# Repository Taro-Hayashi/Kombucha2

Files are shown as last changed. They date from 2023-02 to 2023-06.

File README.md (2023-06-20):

# Kombucha ジョイスティック 左手向けビルドガイド（[右手向け](README_R.md)）
- [キット内容](#キット内容)
- [準備](#準備)
- [はんだ付け](#はんだ付け)
- [組み立て](#組み立て)
- [カスタマイズ](#カスタマイズ)
- [meishi Trackball Moduleを使う](#meishi-Trackball-Moduleを使う)
- [その他](#その他)

## キット内容
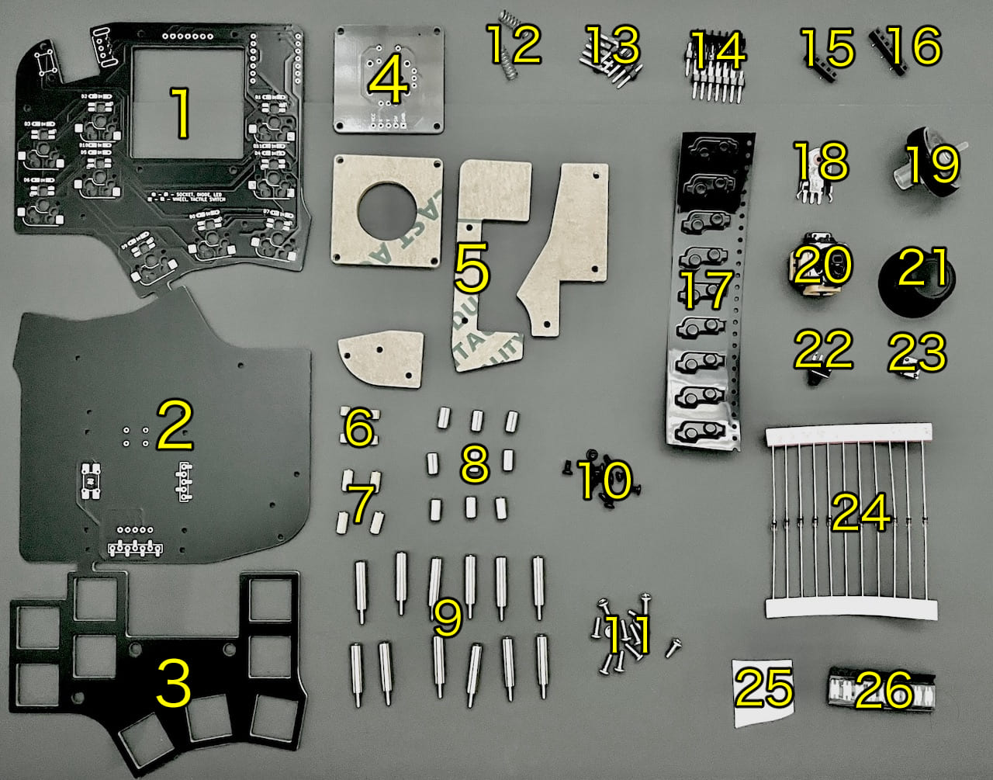
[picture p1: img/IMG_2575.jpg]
  
||部品名|数| |
|-|-|-|-|
|1|メインボード|1||
|2|トッププレート|1||
|3|ボトムプレート|1||
|4|ジョイスティック基板|1||
|5|アクリルプレート|4||
|6|スペーサー（細）（短）|4|黄銅・3mm|
|7|スペーサー（細）（長）|4|黄銅・7mm|
|8|スペーサー（太）（短）|9|ステンレス・7mm|
|9|スペーサー（太）（長）|12|ステンレス・16mm|
|10|ねじ（短）|14|黒|
|11|ねじ（長）|12|銀|
|12|スプリング|2||
|13|ピンヘッダ（短）|2|5ピン|
|14|ピンヘッダ（長）|1|7 or 8ピン|
|14|7ピンヘッダ|2|XIAO RP2040用|
|15|ピンソケット（短）|1||
|16|ピンソケット（長）|1||
|17|スイッチソケット|9||
|18|ホイールエンコーダー|1|11mm|
|19|ホイール|1||
|20|ジョイスティック|1||
|21|キャップ|1||
|22|タクタイルスイッチ|1|7.5mm|
|23|タクタイルスイッチSMD|1|7mm|
|24|ダイオード|11||
|25|LED|9||
|26|ゴム足|4|

### キット以外に必要なもの
|部品名|数||
|-|-|-|
|XIAO RP2040|1|[TALP KEYBOARD](https://talpkeyboard.net/items/63534f58f5197322fceb6487)、[秋月電子通商](https://akizukidenshi.com/catalog/g/gM-17044/)|
|Cherry MX互換キースイッチ|1|[TALP KEYBOARD](https://talpkeyboard.net/?category_id=5f2d0726afaa9d40152b2cec)、[遊舎工房](https://shop.yushakobo.jp/search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)|
|Cherry MX互換キーキャップ（1U）|1|[TALP KEYBOARD](https://stores.jp/search?q=チェリーMX&store=talpkeyboard)、[遊舎工房](https://shop.yushakobo.jp/collections/keycaps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特殊&filter.v.price.gte=&filter.v.price.lte=)|
|Type-C USB ケーブル|1|[遊舎工房](https://shop.yushakobo.jp/products/usb_type_a_to_c_cable?_pos=3&_sid=d2e0de26b&_ss=r)、[秋月電子通商](https://akizukidenshi.com/catalog/g/gC-13563/)、100円均一など|
 
### 必要な工具
|工具名|
|-|
|はんだごて|
|はんだ|
|精密ドライバー|
|ニッパー|

## 準備
<!-- 
### プレートを切り離す
メインボード、トッププレート、ボトムプレートを切り離します。そのまま折るだけでも割れますがカッターなどで切れ目を入れると入れる力が少なくて済みます。  
![](img/) 
ニッパーでバリを取り切断面を棒やすりで綺麗にします。  
![](img/)
-->
### 左右を決める
このキットは基板の表裏を変えることで左手用と右手用を作り分けることができます。   
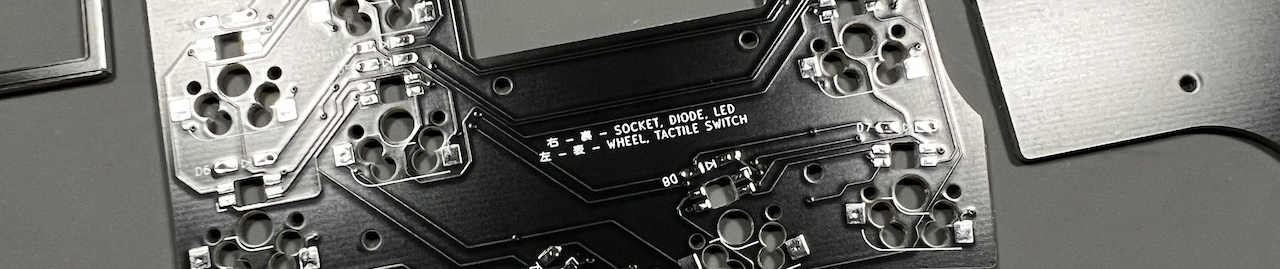
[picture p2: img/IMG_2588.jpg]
 
どちらの面にどの部品を実装するかが基板に書いてあるので参考にしてください。   

基板には初期型と後期型が存在し、2023年5月分の在庫では混在しています（今後は後期型に統一されます）。後期型の場合基板に書いてありますのでご確認ください。

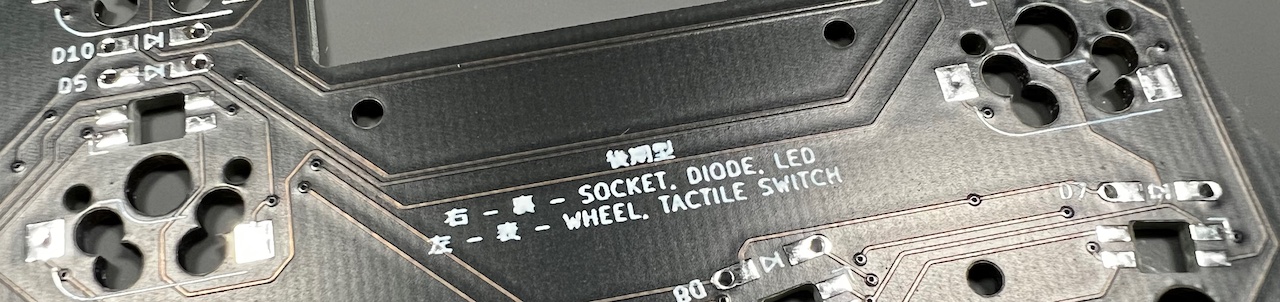
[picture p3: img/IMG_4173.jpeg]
 

### XIAO RP2040にテストファームウェアを書き込む  
こちらのファイルをダウンロードしてください。  
- [tarohayashi_kombucha_stick_default.uf2](https://github.com/Taro-Hayashi/Kombucha2/releases/download/0.20.7/tarohayashi_kombucha_stick_default.uf2)

基板上の右のBのボタンを押しながらPCに接続するとRPI-RP2というドライブとして認識されます。  
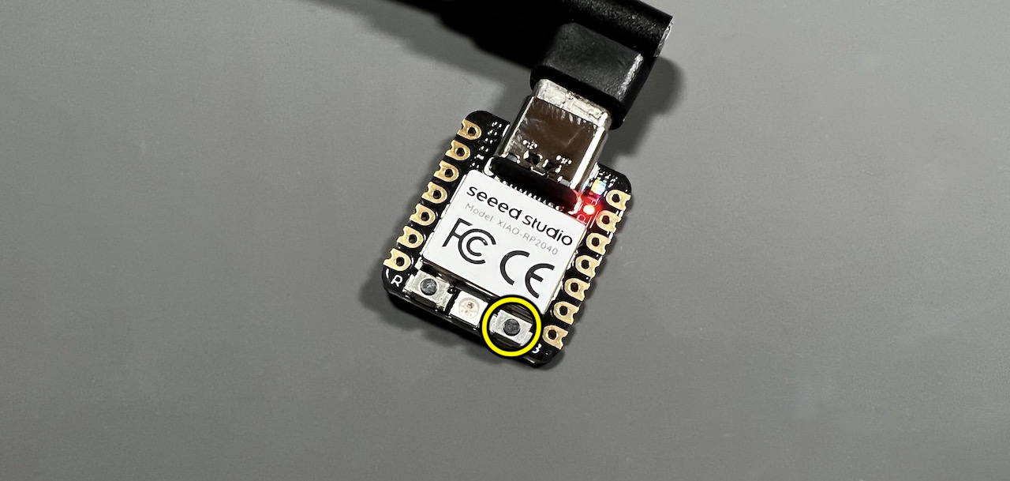
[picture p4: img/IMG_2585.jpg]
 
ダウンロードしたファイルを書き込むとXIAO RP2040をキーボードとして使えるようになります。  

## はんだ付け
### ボトムプレートのはんだ付け
左右を確認してボトムプレートにピンソケット2つをはんだ付けします。    
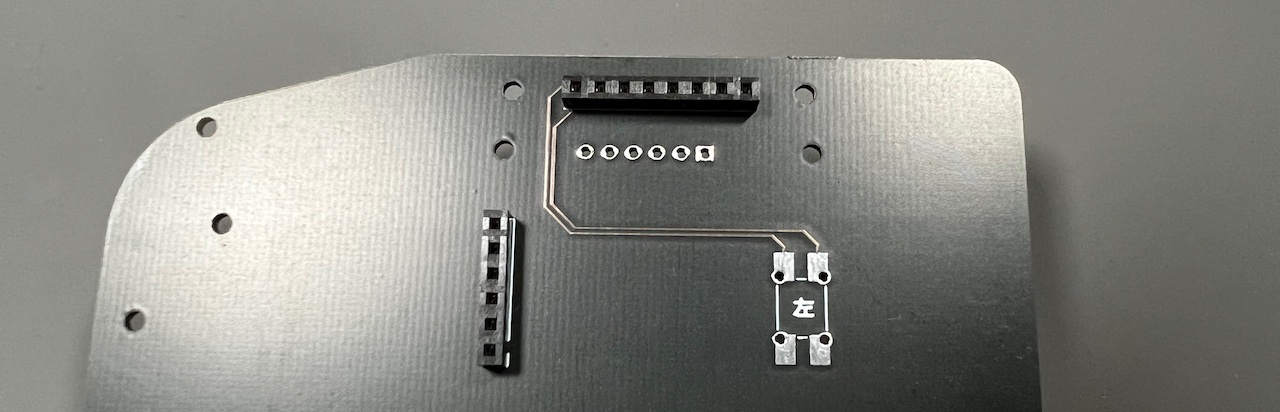
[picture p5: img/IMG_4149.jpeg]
 

ボトムプレートのピンソケットと同じ面にスペーサー（太）（短）をねじ（短）で止めます。黄丸の４箇所にはスペーサー（細）（長）を使います。  
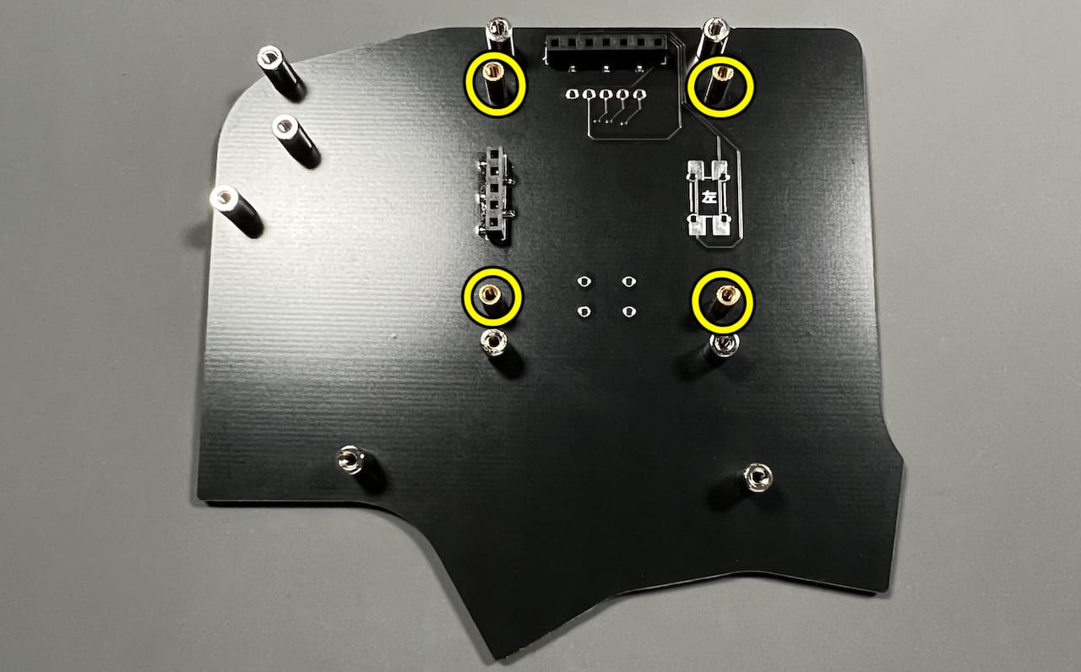
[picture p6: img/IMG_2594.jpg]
 
反対の面にはゴム足を貼ります。  
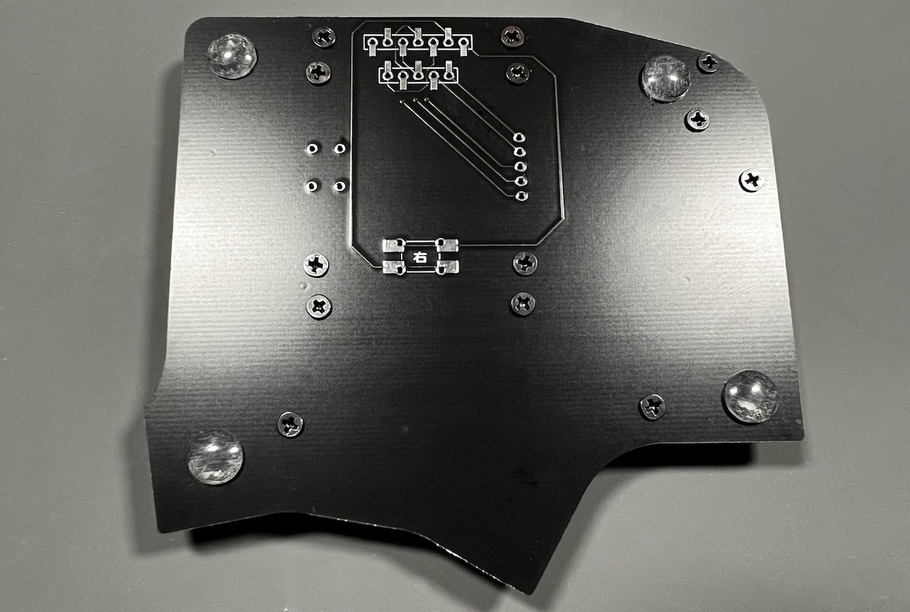
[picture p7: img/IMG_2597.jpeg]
 

### ジョイスティック基板のはんだ付け
ジョイスティック基板にジョイスティックをはんだ付けします。  
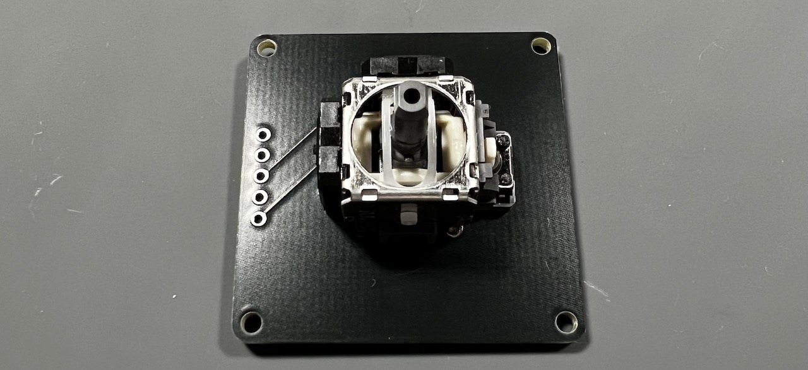
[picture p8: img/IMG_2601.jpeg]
 
ジョイスティックが中央に戻らないことがありますが、アクリルプレートを取り付ける前の正常な動作です。  

ボトムプレートのピンソケットに5ピンヘッダを立てます。短い方を差しました。  
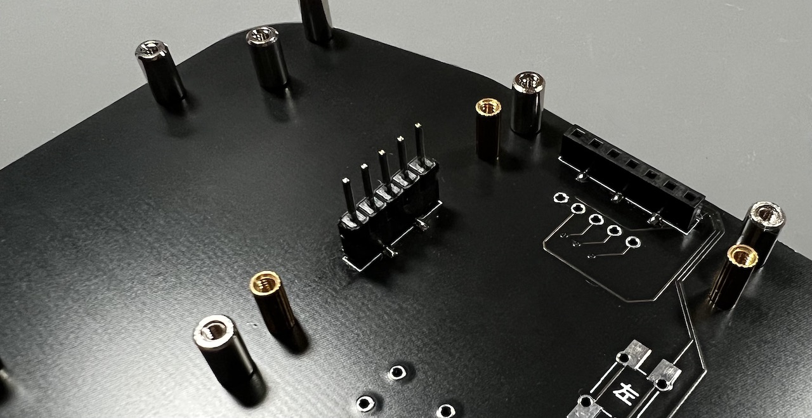
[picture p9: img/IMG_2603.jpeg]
 
後期型の場合は画像のピンを開けて差し込んでください。違っているとネジ穴が合わないので確認してから半田付けしてください。
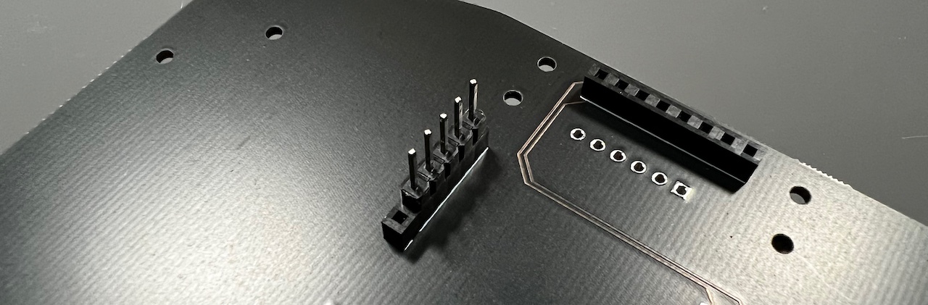
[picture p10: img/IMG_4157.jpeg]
 

ジョイスティック基板をスペーサー（細）（長）の上にのせ、スペーサー（太）（長）でボトムプレートに固定します。  
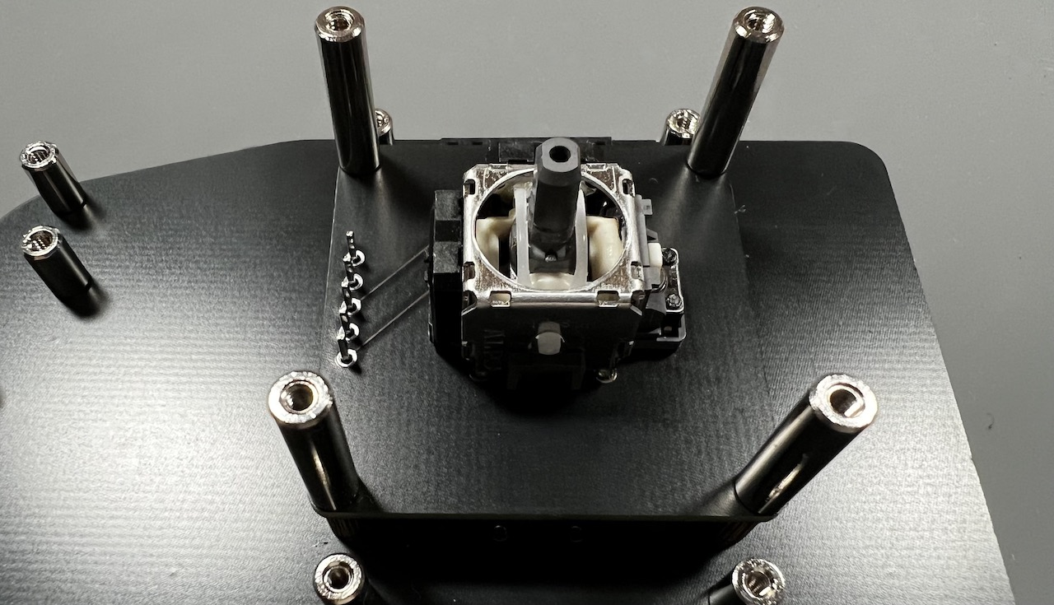
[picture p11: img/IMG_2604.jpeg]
 

飛び出たピンヘッダをニッパーで切りはんだ付けしましょう（ギリギリまで切りすぎるとうまくはんだ付けできないことがあります）。   
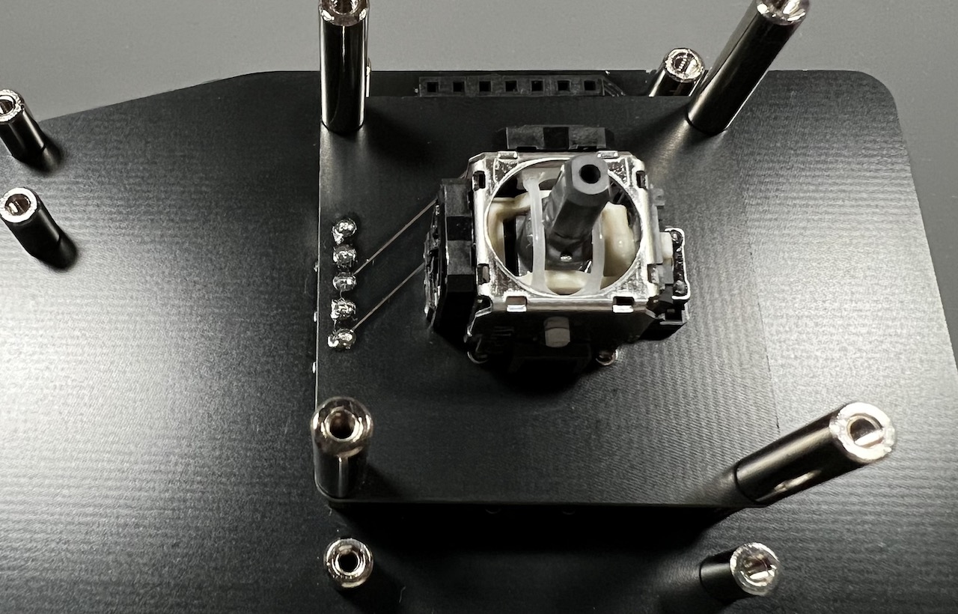
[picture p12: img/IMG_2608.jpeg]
 

ジョイスティックにキャップを取り付けます。  
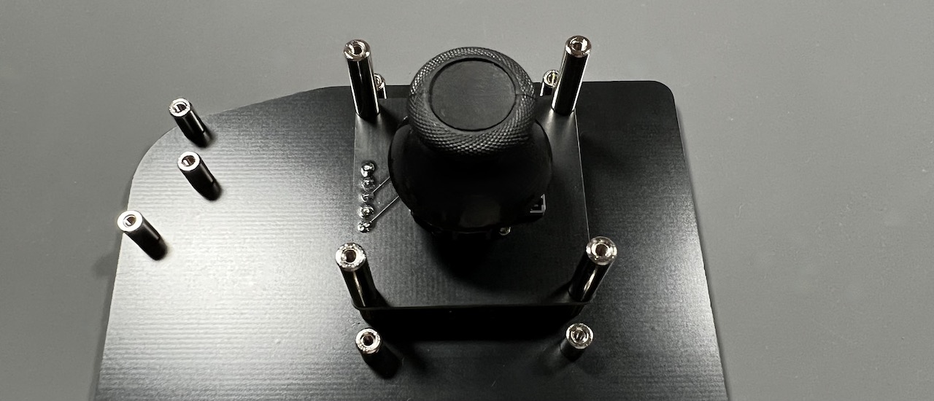
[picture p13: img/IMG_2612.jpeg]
 

### メインボードのはんだ付け
LEDをはんだ付けします。欠けている方向と白い線が合うように置きます。  
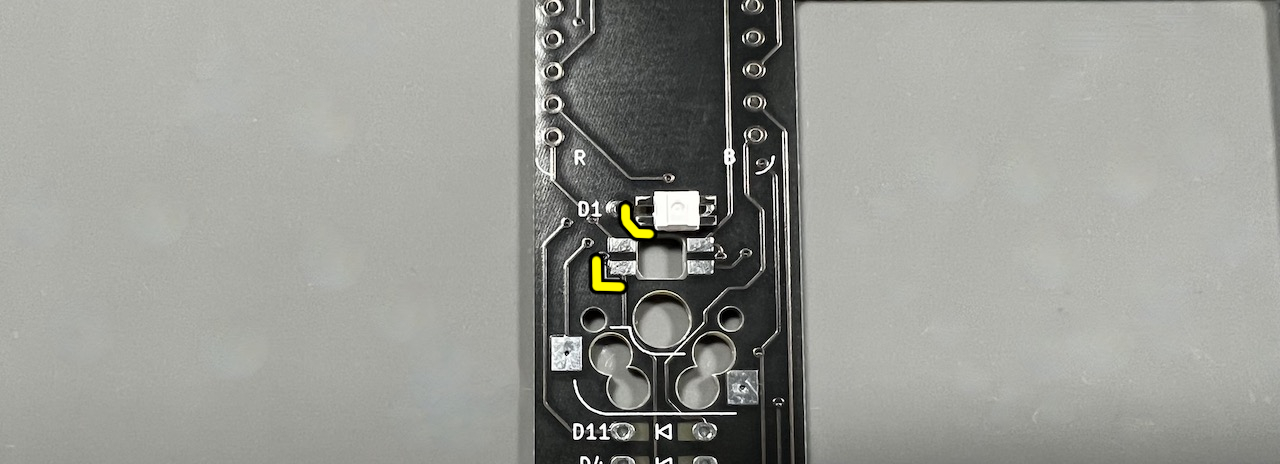
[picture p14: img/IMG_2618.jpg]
   

XIAO RP2040を7ピンヘッダーではんだ付けします。両面をはんだ付けします。  
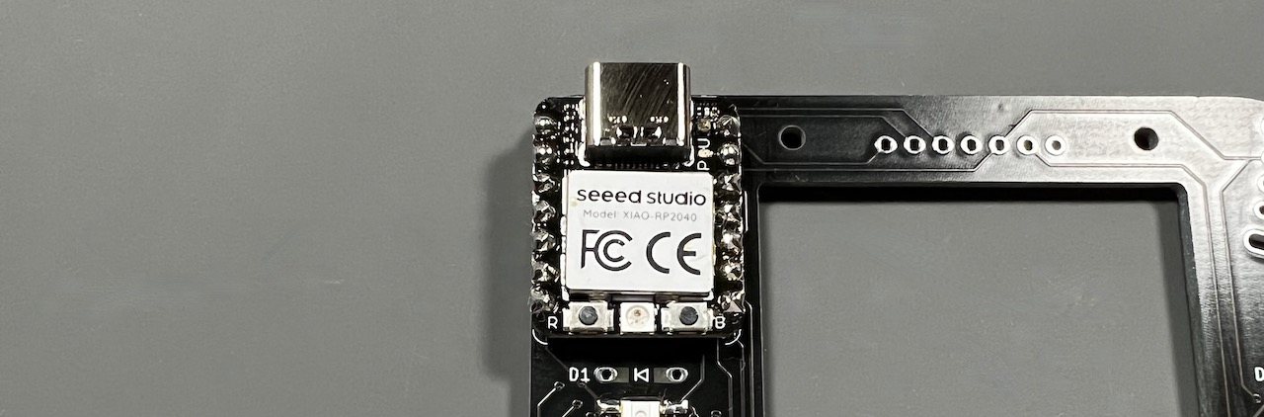
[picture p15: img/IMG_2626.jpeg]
 

USBケーブルを接続してLEDが発光することを確かめてください。光らない場合は向きが間違っていたりどこかでショートしていたりはんだ付けが足りない可能性があります。  
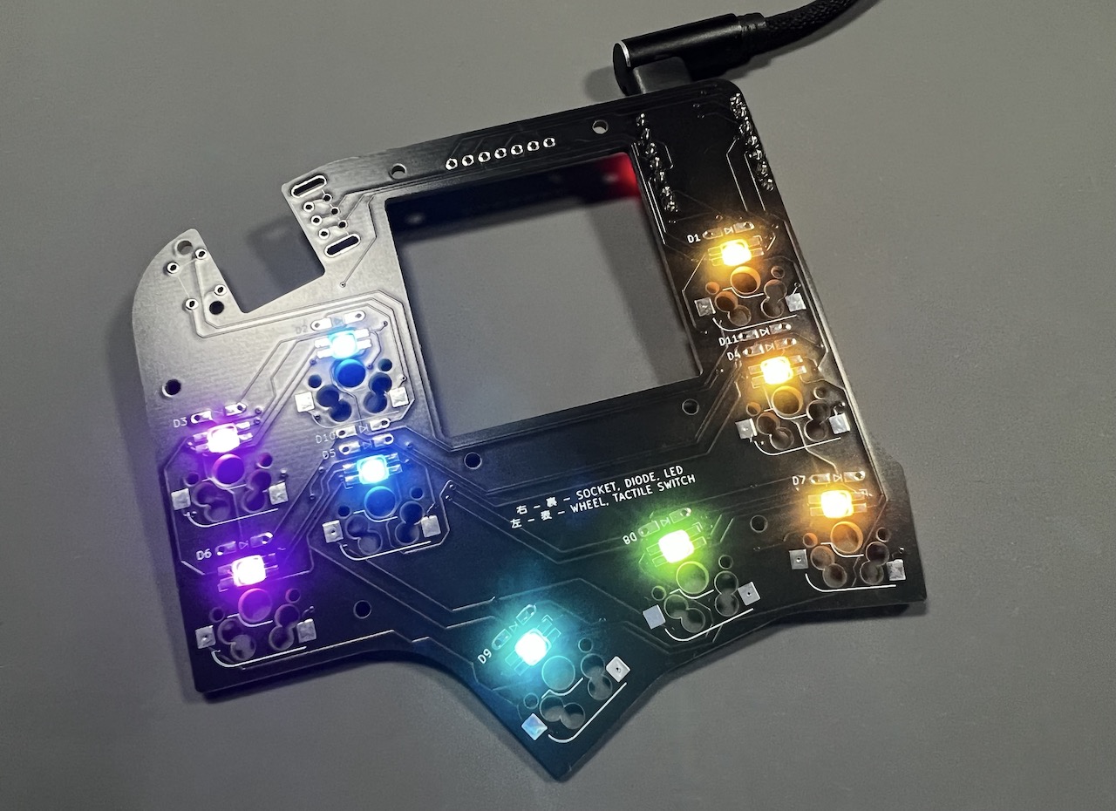
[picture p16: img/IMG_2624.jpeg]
  
  
USBケーブルを抜いてください。はんだ付けの作業は通電していない状態で行います。  
この後も部品を取り付けるごとにその部品の動作を確認するとトラブルの原因を突き止めやすいです。   
    
ダイオードを折り曲げて差し込み、固定するためにさらに曲げます。表裏を指定してありますがどちら側でも構いません。  
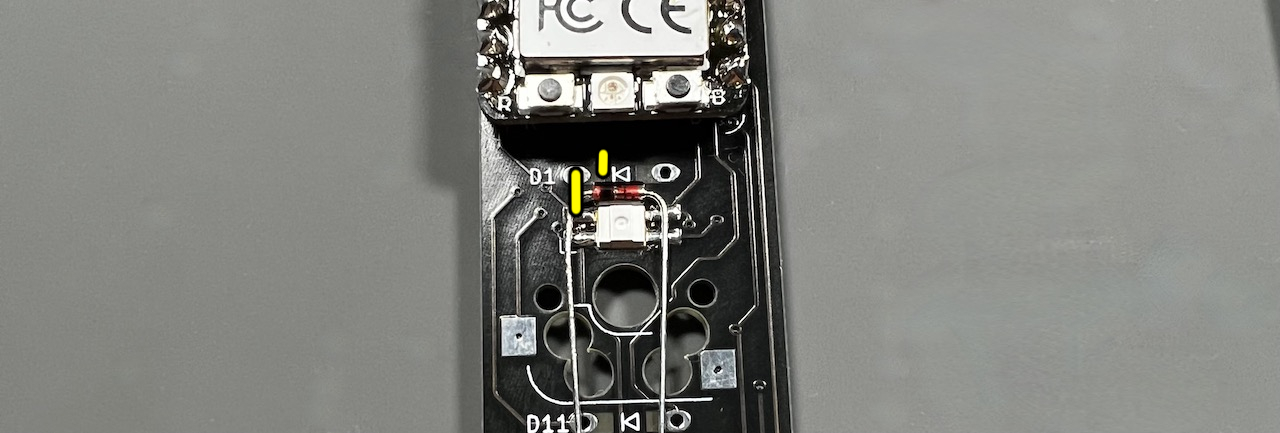
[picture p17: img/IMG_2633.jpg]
 
ダイオードには向きがあるので、黒線と基板の矢印の向きを合わせてください。  

はんだ付けをしたら足をニッパーで切ります。  
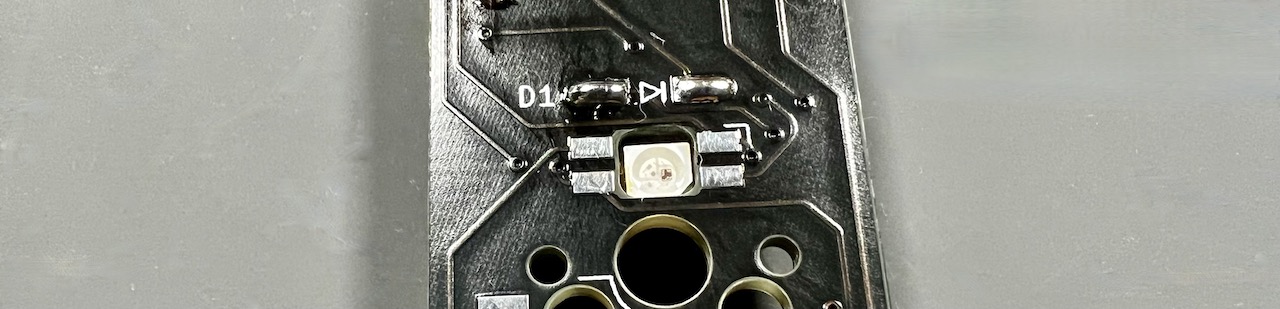
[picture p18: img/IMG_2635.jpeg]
 

スイッチソケットをはんだ付けします。裏表に注意してください。  
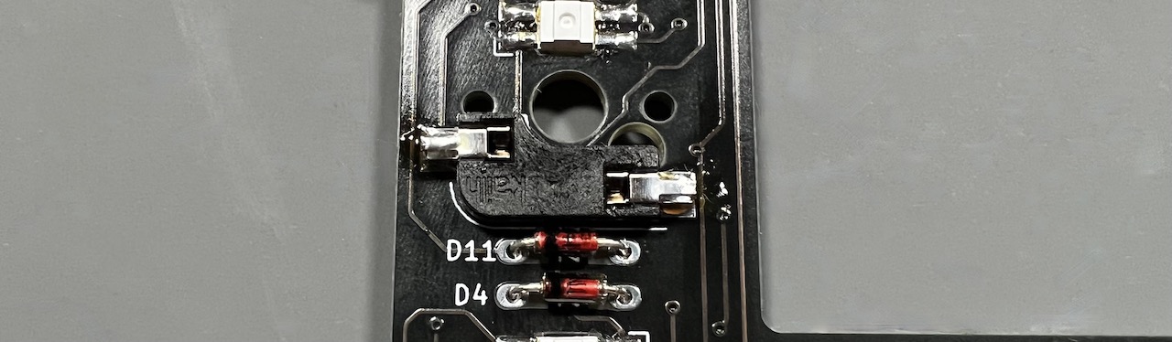
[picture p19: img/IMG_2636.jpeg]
 

メインボードにホイールエンコーダーとタクタイルスイッチ（足が下に伸びている方）をはんだ付けします。表裏に注意してください。  
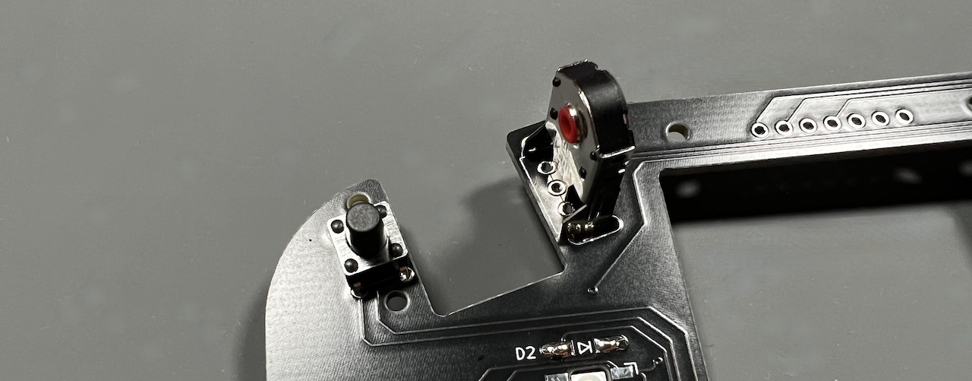
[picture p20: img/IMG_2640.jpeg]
 

ボトムプレートにピンヘッダを差し込みます。  
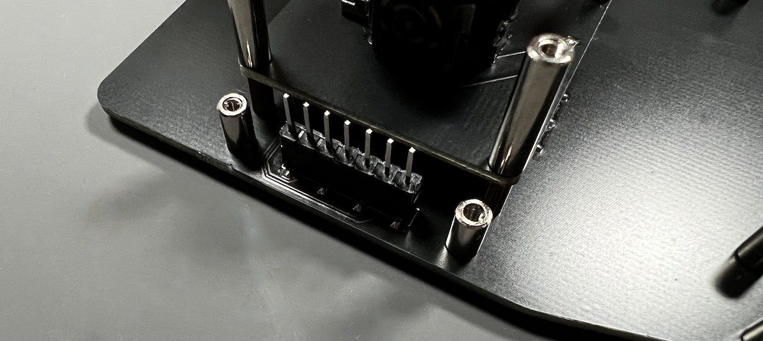
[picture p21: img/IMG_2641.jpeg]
 

ボトムプレートにメインボードを載せ、スペーサー（太）（長）でボトムプレートに固定します。トッププレートで隠れる黄丸の一箇所だけはねじ（短）で止めます。  
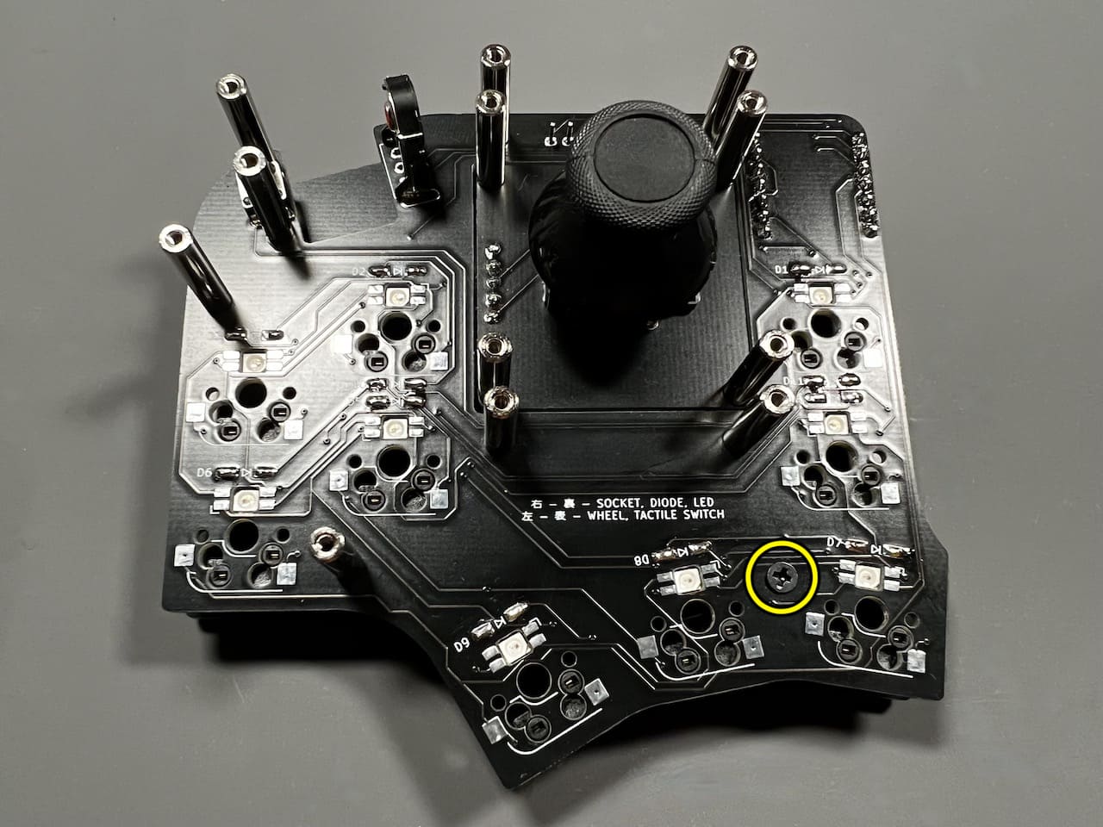
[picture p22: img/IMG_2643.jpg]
 
飛び出たピンヘッダをニッパーで切ってはんだ付けしましょう。テストファームウェアではジョイスティックは動作しません。  

トッププレートの4隅にスイッチを差し込みます。差し込みが硬い場合はここですべてのスイッチを固定してしまう方がいいかもしれません（スイッチの種類によって変わります）。  
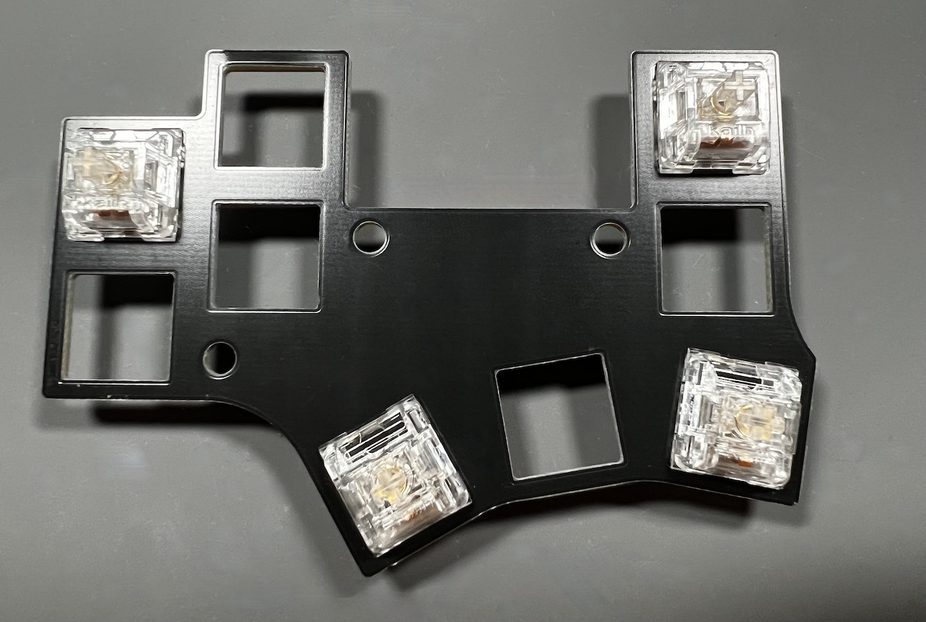
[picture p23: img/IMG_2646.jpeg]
 

スペーサーを通してメインボードに乗せ、キースイッチがスイッチソケットに入るように押し込みます。  
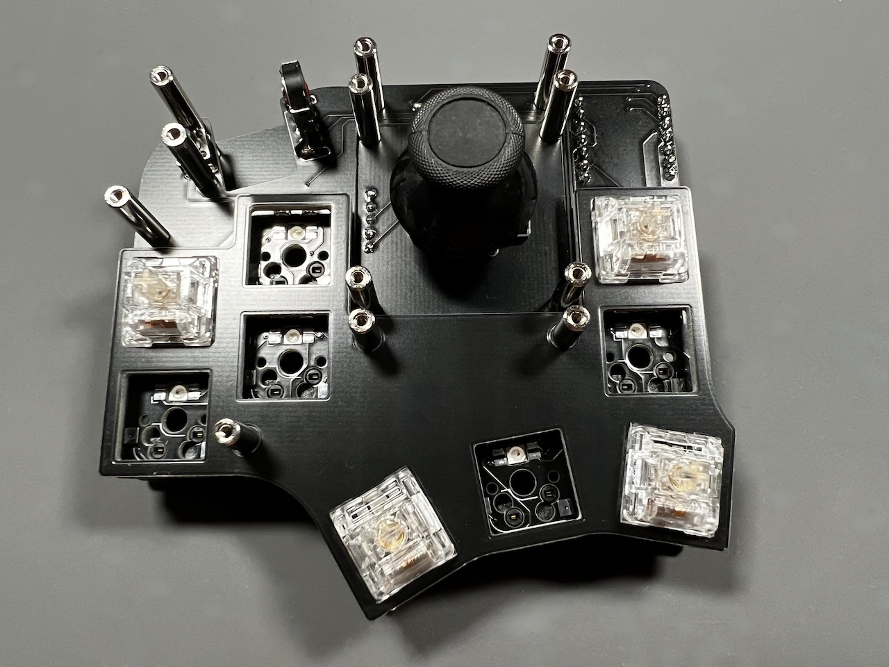
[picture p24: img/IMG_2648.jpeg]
 
キースイッチのピンが曲がらないように気をつけてください。  

全てのスイッチを差し込み、ホイールをホイールエンコーダーに差し込みます。  
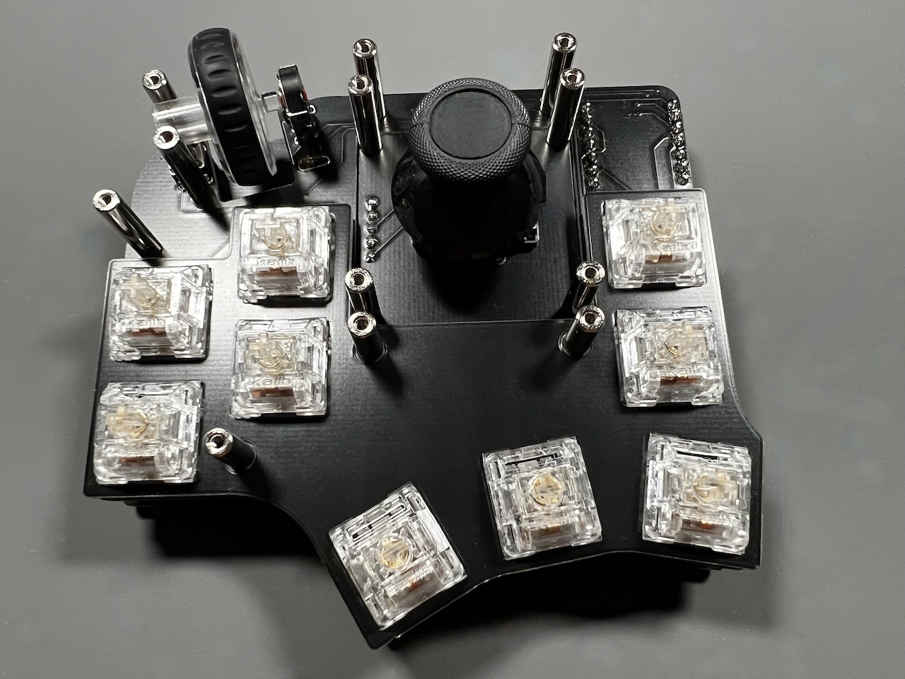
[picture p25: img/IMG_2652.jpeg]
 

アクリルプレートから保護フィルムを剥がして、ねじ（長）で止めます。  
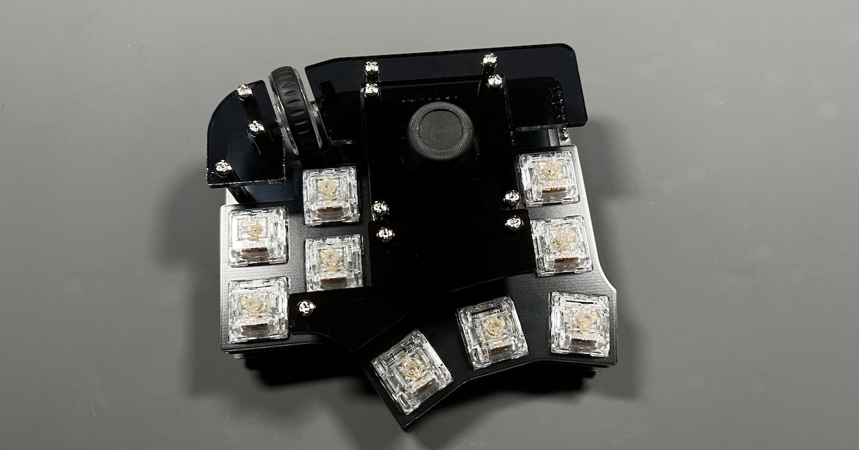
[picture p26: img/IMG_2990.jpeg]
 

キーキャップをつけて完成です。
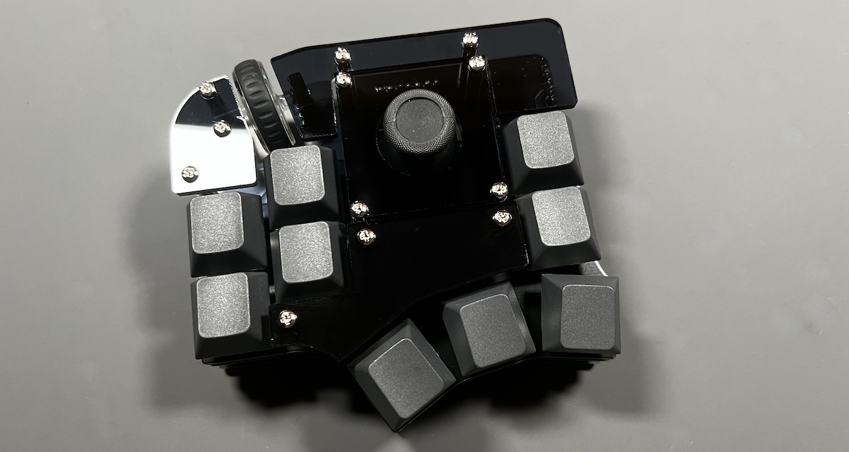
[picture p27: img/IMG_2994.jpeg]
 
こちらのファームウェアを書き込んでください。XIAO RP2040のBのスイッチを押す代わりに、XIAO RP2040に一番近いキーを押しながらUSBケーブルを繋ぐことでRPI-RP2のドライブを出すことが出来ます。  
- [tarohayashi_kombucha_stick_stick.uf2](https://github.com/Taro-Hayashi/Kombucha2/releases/download/0.20.7/tarohayashi_kombucha_stick_stick.uf2)
- 後期型向け [tarohayashi_kombucha_stick_stick.uf2](https://github.com/Taro-Hayashi/Kombucha2/releases/download/0.20.8/tarohayashi_kombucha_stick_stick.uf2)

## カスタマイズ
LEDを消したい時は親指クラスタ（最下段）の奥のキーを押しながらジョイスティックを押し込んでください。  
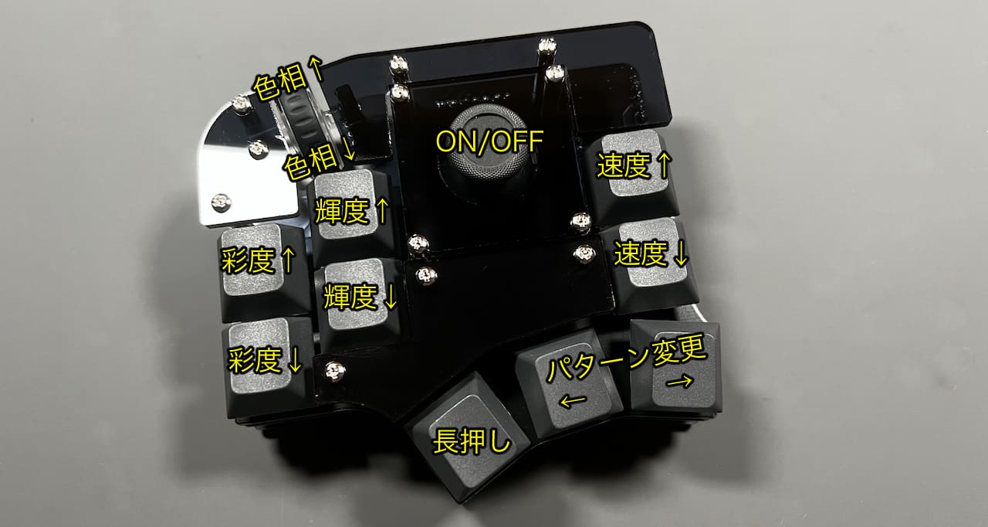
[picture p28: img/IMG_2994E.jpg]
 

ジョイスティックを含めた全てのキーはVIAというWebサイト（もしくはアプリケーション）で好きなものに変更することができます。  
こちらのJSONファイルをダウンロードしてください。 
- [kombucha.json](https://github.com/Taro-Hayashi/Kombucha2/releases/download/0.20.0/kombucha.json)

Google Chrome（Microsoft Edge）を利用して下記webサイトにアクセスするか、VIAのアプリケーションをダウンロードして起動してください。  
- [Web版VIA（Google Chromeでアクセスしてください）](https://usevia.app/#/design)
- [アプリ版VIA](https://github.com/the-via/releases/releases)

DESIGNタブのLoadでダウンロードしたJSONファイルを読み込ませるとキーの変更が出来るようになります（アプリ版ではまずShow Design tabをオンにしてください）。  
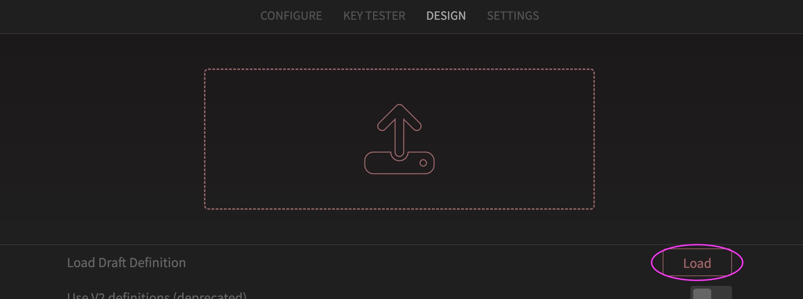
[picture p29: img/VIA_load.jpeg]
  
CONFIGUREタブのAuthorize device+からKombuchaを追加してください。  

### 左右の変更
LAYOUTSから見た目の左右を変更することができます。  
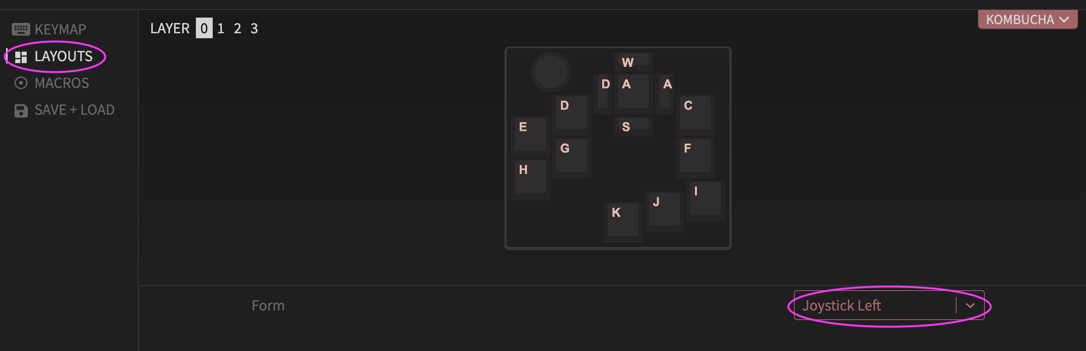
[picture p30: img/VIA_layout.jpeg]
  

### ホイールの割り当てキー
キーマップ変更画面で上部の丸をクリックするとホイールを回転させた時と押し込んだ時に入力されるキーを変更することができます。  
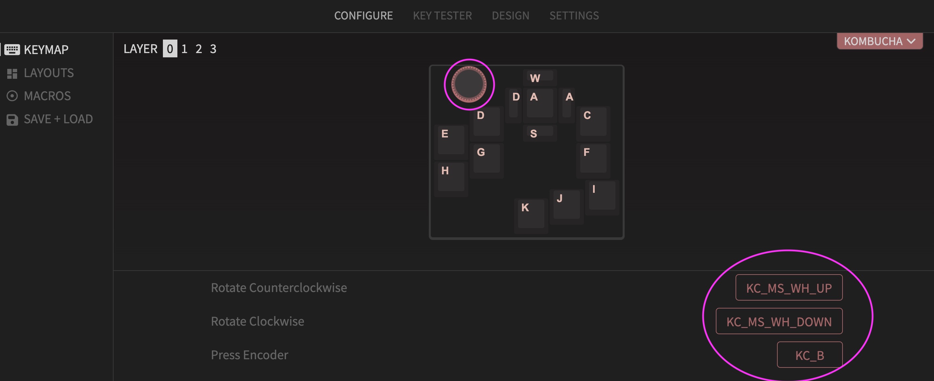
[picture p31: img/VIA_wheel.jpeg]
  

### その他の利用方法
ジョイスティックでマウスカーソルを動かすことも可能で、その場合はこちらのファイルをダウンロードしてファームウェアを書き換えてください。 
- [tarohayashi_kombucha_stick_cursor.uf2](https://github.com/Taro-Hayashi/Kombucha2/releases/download/0.20.7/tarohayashi_kombucha_stick_cursor.uf2)
- 後期型向け [tarohayashi_kombucha_stick_cursor.uf2](https://github.com/Taro-Hayashi/Kombucha2/releases/download/0.20.8/tarohayashi_kombucha_stick_cursor.uf2)

認識が不安定ですが、こちらのファームウェアを書き込むことでKombuchaをゲームパッドとして認識させることもできます。  
- [tarohayashi_kombucha_sitck_joypad_fix.uf2](https://github.com/Taro-Hayashi/Kombucha2/releases/download/0.20.7/tarohayashi_kombucha_stick_joypad.uf2)

標準では親指クラスタの真ん中のキーを長押しするとカーソル/ジョイパッドの方向を変更できます。
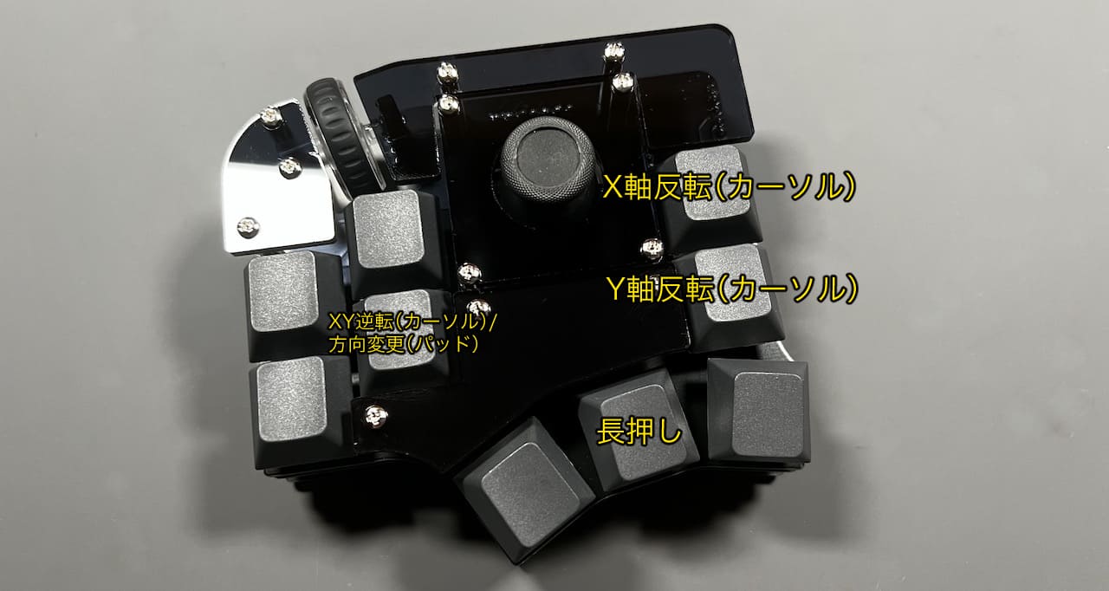
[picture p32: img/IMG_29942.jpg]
 
|機能（カーソル）|機能（パッド）|キーコード|
|-|-|-|
|X軸反転||CUSTOM(65)|
|Y軸反転||CUSTOM(66)|
|XY逆転|方向変更|CUSTOM(67)|

SPECIALタブのAnyで割り当てることができます。
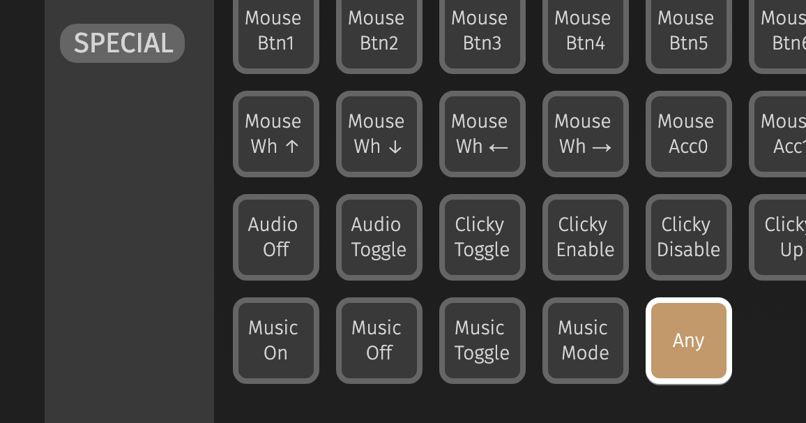
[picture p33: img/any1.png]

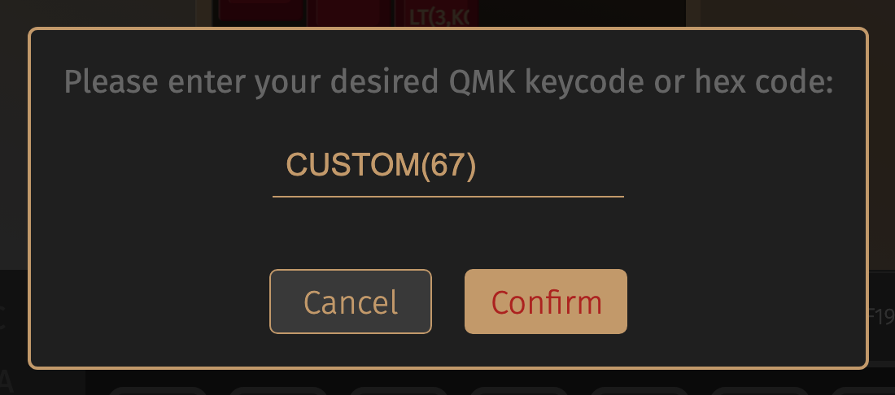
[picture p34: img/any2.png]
 
  
#### ジョイスティックの補正
WindowsではスタートメニューにJOY.CPLと打ち込むとスティックの補正ができます。  
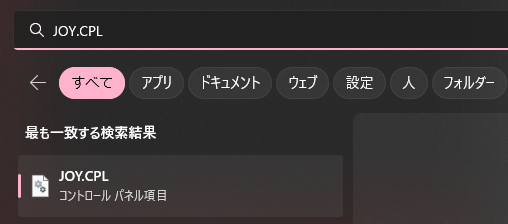
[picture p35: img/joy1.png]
   
プロパティから調整を選びウィザードに従ってください。  
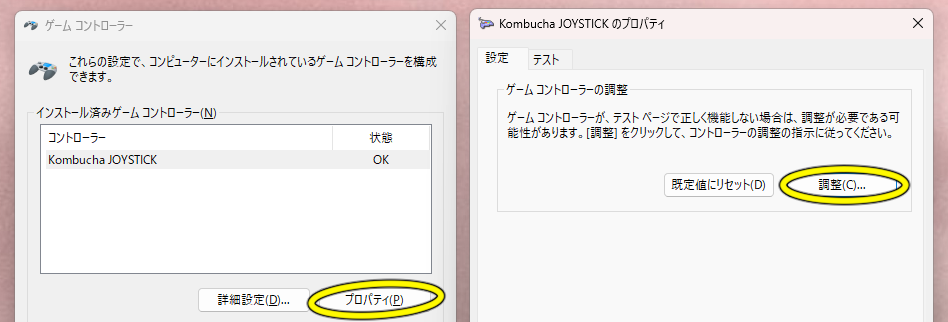
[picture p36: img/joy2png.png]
    
上手く動かない場合はゲームパッドとしてではなく通常のファームウェアにカーソルキーやWASDを割り当ててお使いください。  

## meishi Trackball Moduleを使う
### はんだ付け
一度分解し、ボトムプレートにタクタイルスイッチSMDをはんだ付けします。
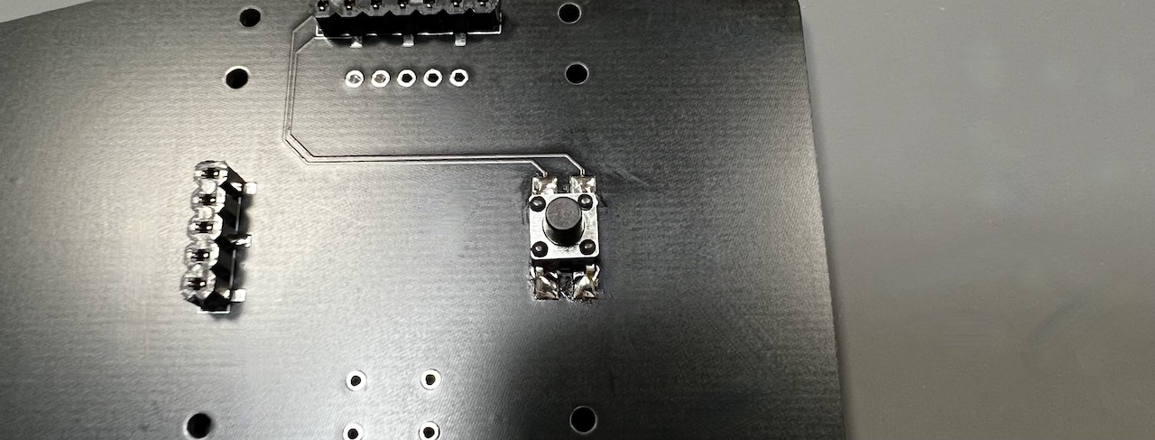
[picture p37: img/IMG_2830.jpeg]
  
ピンヘッダーが有る側の2箇所はスペーサー（細）（長）、無い側の2箇所はスペーサー（細）（短）をねじ止めします。
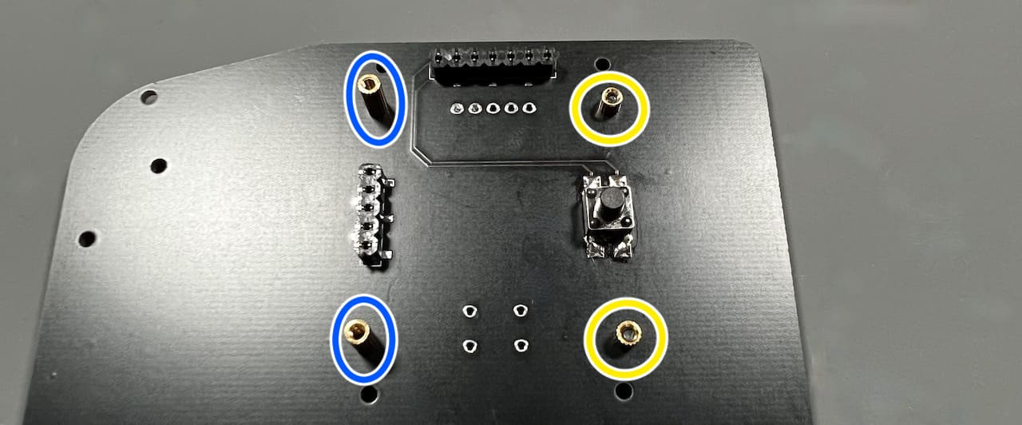
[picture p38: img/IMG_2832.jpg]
 
meishi Trackball Moduleを基板から切り離してください。  
[meishi Trackball Module互換基板を使う場合はこちらをご覧ください。](mTM.md)  
  
ジョイスティックの時と同様にピンヘッダを立てモジュール付属のねじを使って基板の位置を決めたらはんだ付けします。
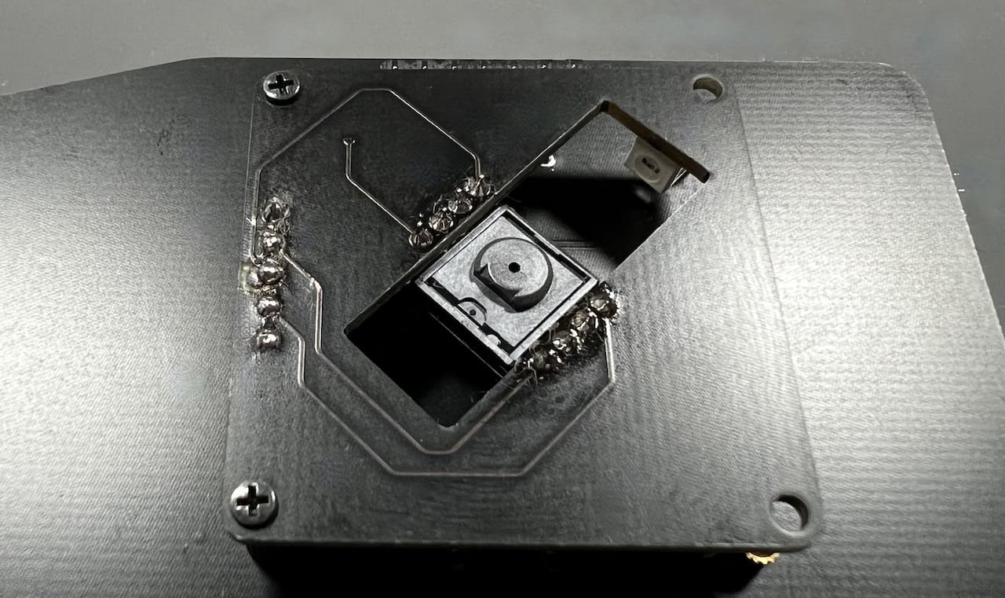
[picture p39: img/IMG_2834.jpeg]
  
後期型の場合は画像のピンを開けて差し込んでください。違っているとネジ穴が合わないので確認してから半田付けしてください。
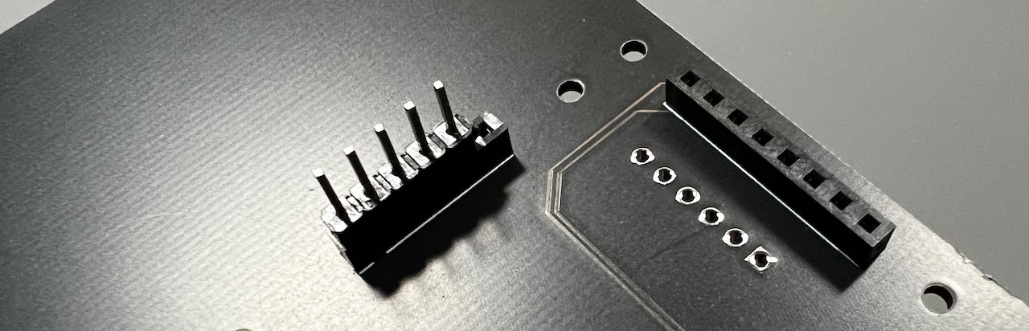
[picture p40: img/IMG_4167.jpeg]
  

はんだ付けをしたらねじを一度はずしてモジュール基板を取り外し、センサーの保護フィルムをはがしてレンズとボールケースを取り付けます。  
  

ピンヘッダーのない側にスペーサー（細）（短）をねじで止めます。  

スペーサーの上にスプリングを立てます。

ねじでスペーサー（細）（長）側も止めるとボールのクリックができるようになります。

組み立て直したら完成です。


ファームウェアはこちらをお使いください。  
- [tarohayashi_kombucha_ball_via.uf2](https://github.com/Taro-Hayashi/Kombucha2/releases/download/0.20.7/tarohayashi_kombucha_ball_via.uf2)

### トラックボールの調整
標準では親指クラスタの真ん中のキーを押しながらボールの左右のキーを押すとセンサーの感度（CPI）を増減できます。その下のキーを押すとマウスカーソルの上下左右の十字方向と10°の微調整が可能です。

|機能|キーコード|
|-|-|
|CPI増|CUSTOM(65)|
|CPI増|CUSTOM(66)|
|角度増|CUSTOM(67)|
|角度減|CUSTOM(67)|

SPECIALタブのAnyで割り当てることができます。

 

## その他
### ファームウェアのフォルダ
- https://github.com/Taro-Hayashi/qmk_firmware/tree/tarohayashi/keyboards/tarohayashi/kombucha

### ファームウェアまとめ
※5/21 後期版向けのファームウェアを追加しました。
- テスト用 [tarohayashi_kombucha_stick_default.uf2](https://github.com/Taro-Hayashi/Kombucha2/releases/download/0.20.7/tarohayashi_kombucha_stick_default.uf2)
- スティックにキー割り当て [tarohayashi_kombucha_stick_stick.uf2](https://github.com/Taro-Hayashi/Kombucha2/releases/download/0.20.7/tarohayashi_kombucha_stick_stick.uf2)
- スティックにキー割り当て（後期型向け） [tarohayashi_kombucha_stick_stick.uf2](https://github.com/Taro-Hayashi/Kombucha2/releases/download/0.20.8/tarohayashi_kombucha_stick_stick.uf2)
- スティックにマウスカーソル [tarohayashi_kombucha_stick_cursor.uf2](https://github.com/Taro-Hayashi/Kombucha2/releases/download/0.20.7/tarohayashi_kombucha_stick_cursor.uf2)
- スティックにマウスカーソル（後期型向け） [tarohayashi_kombucha_stick_cursor.uf2](https://github.com/Taro-Hayashi/Kombucha2/releases/download/0.20.8/tarohayashi_kombucha_stick_cursor.uf2)
- ジョイパッド[tarohayashi_kombucha_sitck_joypad.uf2](https://github.com/Taro-Hayashi/Kombucha2/releases/download/0.20.8/tarohayashi_kombucha_stick_joypad.uf2)
- トラックボール [tarohayashi_kombucha_ball_via.uf2](https://github.com/Taro-Hayashi/Kombucha2/releases/download/0.20.8/tarohayashi_kombucha_ball_via.uf2)

### VIA用JSON
- [kombucha.json](https://github.com/Taro-Hayashi/Kombucha2/releases/download/0.20.0/kombucha.json)

### アクリルプレートのデータ
DXF、SVG、kicadファイルが入っています。
- [kombucha_acrylic.zip](https://github.com/Taro-Hayashi/Kombucha2/releases/download/0.19.12%2Fdevelop/kombucha_acrylic.zip)

### 謝辞
aki27さんのコードを参考にトラックボール用のファームウェアを書きました。
- URL　https://github.com/aki27kbd/qmk_firmware
- ライセンス https://github.com/aki27kbd/qmk_firmware/blob/master/LICENSE

### 販売サイト  
- BOOTH: https://tarohayashi.booth.pm/items/3252673

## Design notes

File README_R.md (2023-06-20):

# Kombucha ジョイスティック 右手向けビルドガイド（[左手向け](README.md)）
- [キット内容](#キット内容)
- [準備](#準備)
- [はんだ付け](#はんだ付け)
- [組み立て](#組み立て)
- [カスタマイズ](#カスタマイズ)
- [meishi Trackball Moduleを使う](#meishi-Trackball-Moduleを使う)
- [その他](#その他)

## キット内容
  
||部品名|数| |
|-|-|-|-|
|1|メインボード|1||
|2|トッププレート|1||
|3|ボトムプレート|1||
|4|ジョイスティック基板|1||
|5|アクリルプレート|4||
|6|スペーサー（細）（短）|4|黄銅・3mm|
|7|スペーサー（細）（長）|4|黄銅・7mm|
|8|スペーサー（太）（短）|9|ステンレス・7mm|
|9|スペーサー（太）（長）|12|ステンレス・16mm|
|10|ねじ（短）|14|黒・4mm|
|11|ねじ（長）|12|銀|
|12|スプリング|2||
|13|5ピンヘッダ|2||
|14|7ピンヘッダ|3||
|15|5ピンソケット|1||
|16|7ピンソケット|1||
|17|スイッチソケット|9||
|18|ホイールエンコーダー|1|11mm|
|19|ホイール|1||
|20|ジョイスティック|1||
|21|キャップ|1||
|22|タクタイルスイッチ|1|7.5mm|
|23|タクタイルスイッチSMD|1|7mm|
|24|ダイオード|11||
|25|LED|9||
|26|ゴム足|4|

### キット以外に必要なもの
|部品名|数||
|-|-|-|
|XIAO RP2040|1|[TALP KEYBOARD](https://talpkeyboard.net/items/63534f58f5197322fceb6487)、[秋月電子通商](https://akizukidenshi.com/catalog/g/gM-17044/)|
|Cherry MX互換キースイッチ|1|[TALP KEYBOARD](https://talpkeyboard.net/?category_id=5f2d0726afaa9d40152b2cec)、[遊舎工房](https://shop.yushakobo.jp/search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)|
|Cherry MX互換キーキャップ（1U）|1|[TALP KEYBOARD](https://stores.jp/search?q=チェリーMX&store=talpkeyboard)、[遊舎工房](https://shop.yushakobo.jp/collections/keycaps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特殊&filter.v.price.gte=&filter.v.price.lte=)|
|Type-C USB ケーブル|1|[遊舎工房](https://shop.yushakobo.jp/products/usb_type_a_to_c_cable?_pos=3&_sid=d2e0de26b&_ss=r)、[秋月電子通商](https://akizukidenshi.com/catalog/g/gC-13563/)、100円均一など|
 
### 必要な工具
|工具名|
|-|
|はんだごて|
|はんだ|
|精密ドライバー|
|ニッパー|

## 準備
<!-- 
### プレートを切り離す
メインボード、トッププレート、ボトムプレートを切り離します。そのまま折るだけでも割れますがカッターなどで切れ目を入れると入れる力が少なくて済みます。  
![](img/) 
ニッパーでバリを取り切断面を棒やすりで綺麗にします。  
![](img/)
-->
### 左右を決める
このキットは基板の表裏を変えることで左手用と右手用を作り分けることができます。   
 
どちらの面にどの部品を実装するかが基板に書いてあるので参考にしてください。   

基板には初期型と後期型が存在し、2023年5月分の在庫では混在しています（今後は後期型に統一されます）。  
後期型の場合基板に書いてありますのでご確認ください。作り方が少し変わり、使用するファームウェアが一部異なります。  
 

### XIAO RP2040にテストファームウェアを書き込む  
こちらのファイルをダウンロードしてください。  
- [tarohayashi_kombucha_stick_default.uf2](https://github.com/Taro-Hayashi/Kombucha2/releases/download/0.20.7/tarohayashi_kombucha_stick_default.uf2)

基板上の右のBのボタンを押しながらPCに接続するとRPI-RP2というドライブとして認識されます。  
 
ダウンロードしたファイルを書き込むとXIAO RP2040をキーボードとして使えるようになります。  

## はんだ付け
### ボトムプレートのはんだ付け
左右を確認してボトムプレートにピンソケット2つをはんだ付けします。  
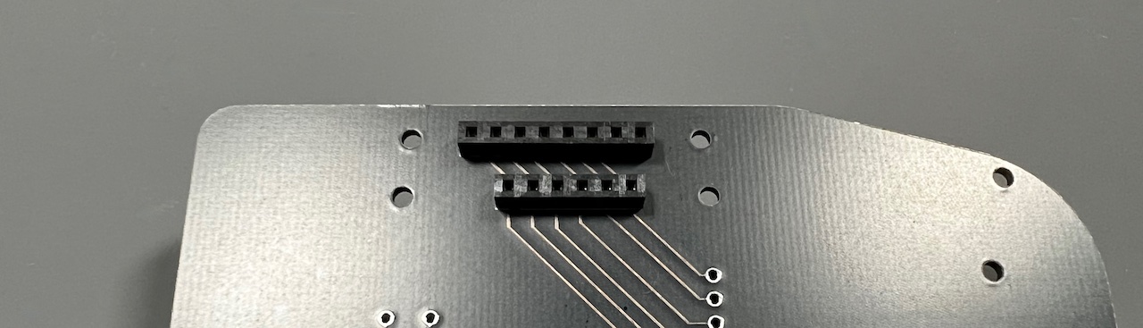
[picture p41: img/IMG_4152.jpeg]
 
位置決めが難しい場合や使っているうちに剥がれた場合などはDIPタイプのピンソケットも使用することができます。  

ボトムプレートのピンソケットと同じ面にスペーサー（太）（短）をねじ（短）で止めます。黄丸の４箇所にはスペーサー（細）（長）を使います。  
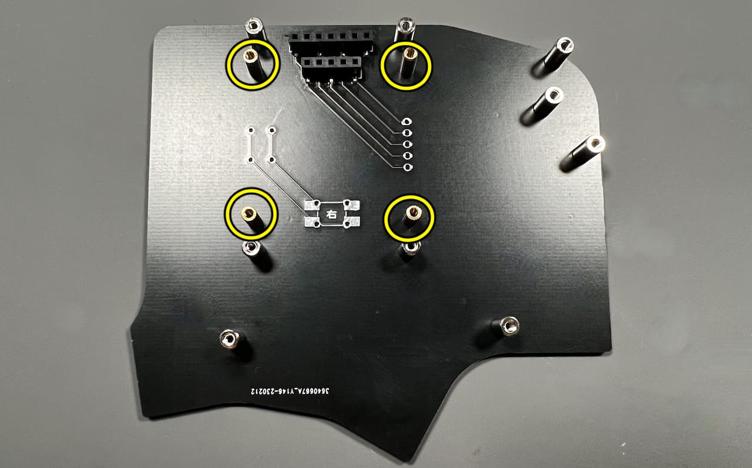
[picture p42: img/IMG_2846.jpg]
 
反対の面にはゴム足を貼ります。  
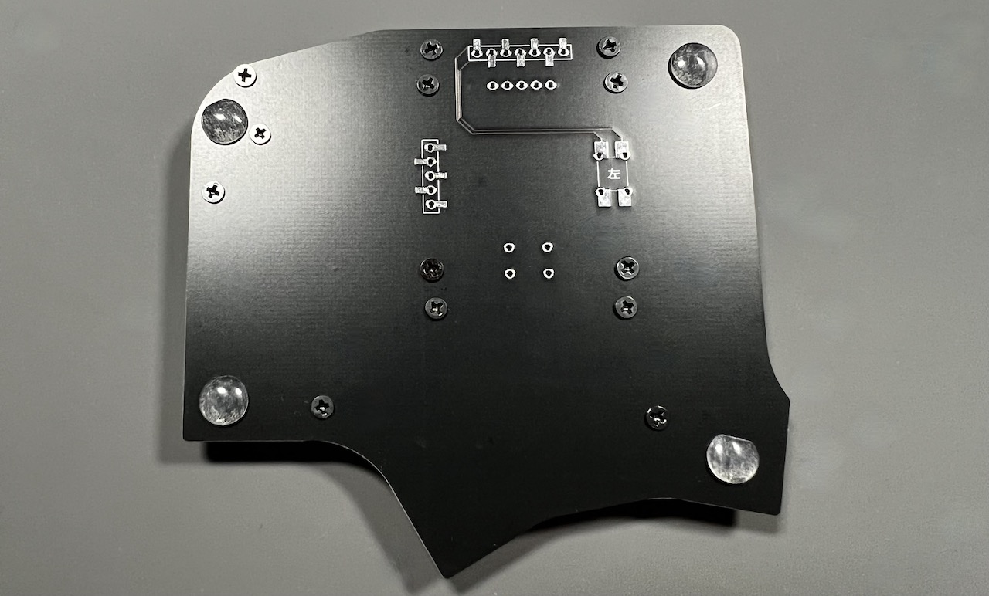
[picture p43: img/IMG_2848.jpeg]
 

### ジョイスティック基板のはんだ付け
ジョイスティック基板にジョイスティックをはんだ付けします。  
 
ジョイスティックが中央に戻らないことがありますが、アクリルプレートを取り付ける前の正常な動作です。  

ボトムプレートのピンソケットに5ピンヘッダを立てます。短い方を差しました。  
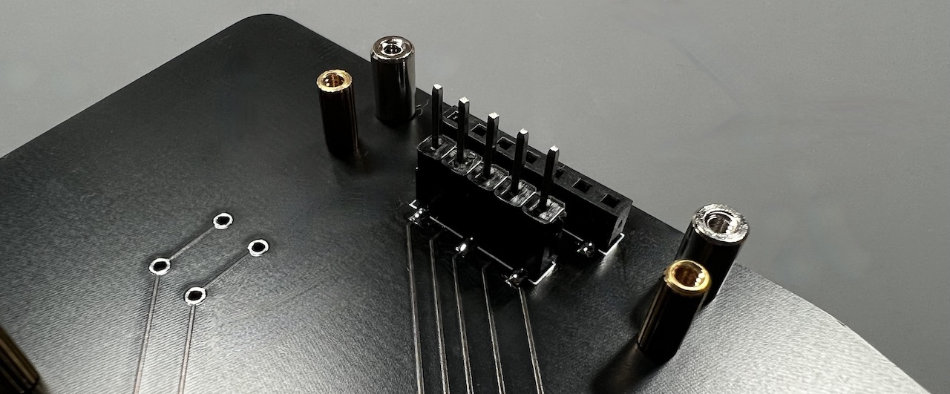
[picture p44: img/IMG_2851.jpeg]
 
後期型の場合は画像のピンを開けて差し込んでください。違っているとネジ穴が合わないので確認してから半田付けしてください。
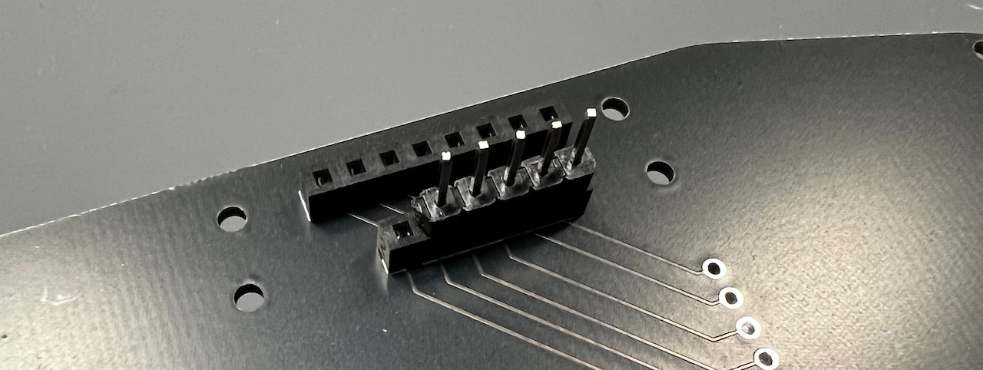
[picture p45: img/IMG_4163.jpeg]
 

ジョイスティック基板をスペーサー（細）（長）の上にのせ、スペーサー（太）（長）でボトムプレートに固定します。  
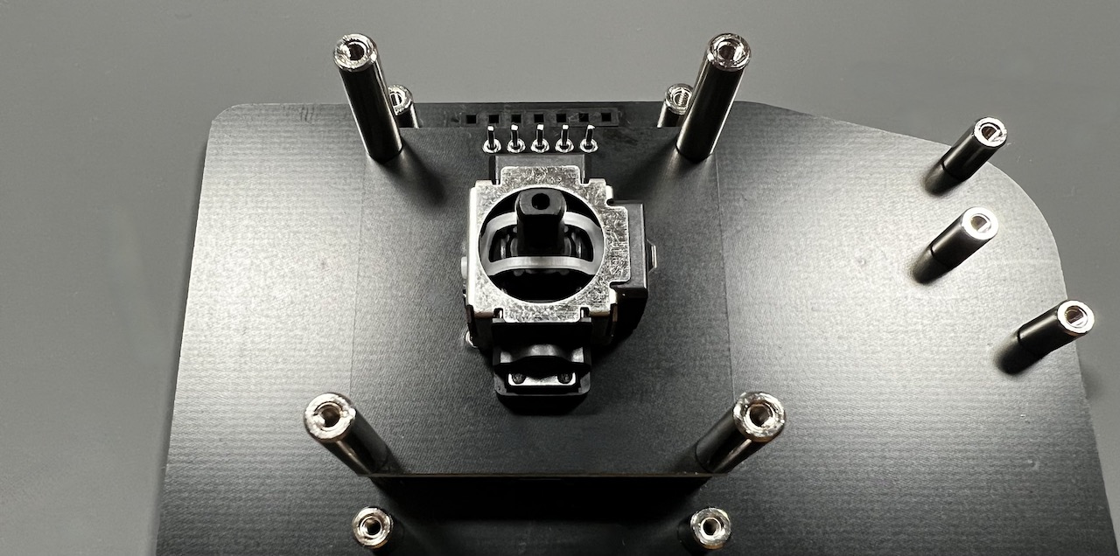
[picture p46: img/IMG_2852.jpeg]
 

飛び出たピンヘッダをニッパーで切りはんだ付けしましょう（ギリギリまで切りすぎるとうまくはんだ付けできないことがあります）。  
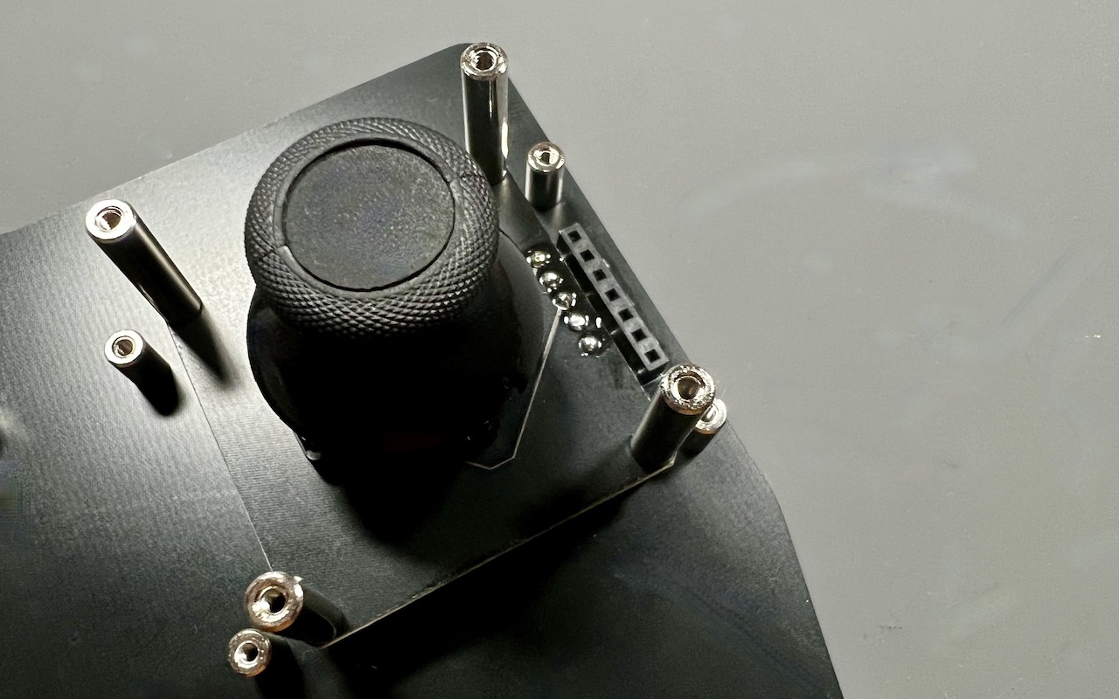
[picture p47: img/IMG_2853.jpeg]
 
ジョイスティックにキャップを取り付けました。  

### メインボードのはんだ付け
LEDをはんだ付けします。欠けている方向と白い線が合うように置きます。  
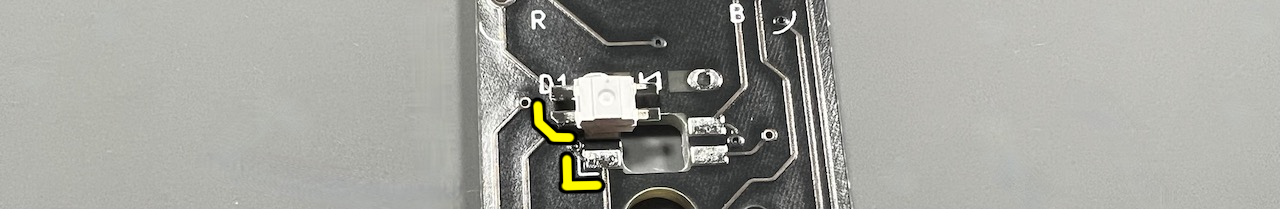
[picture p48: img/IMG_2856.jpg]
   

XIAO RP2040を7ピンヘッダーではんだ付けします。両面をはんだ付けします。   
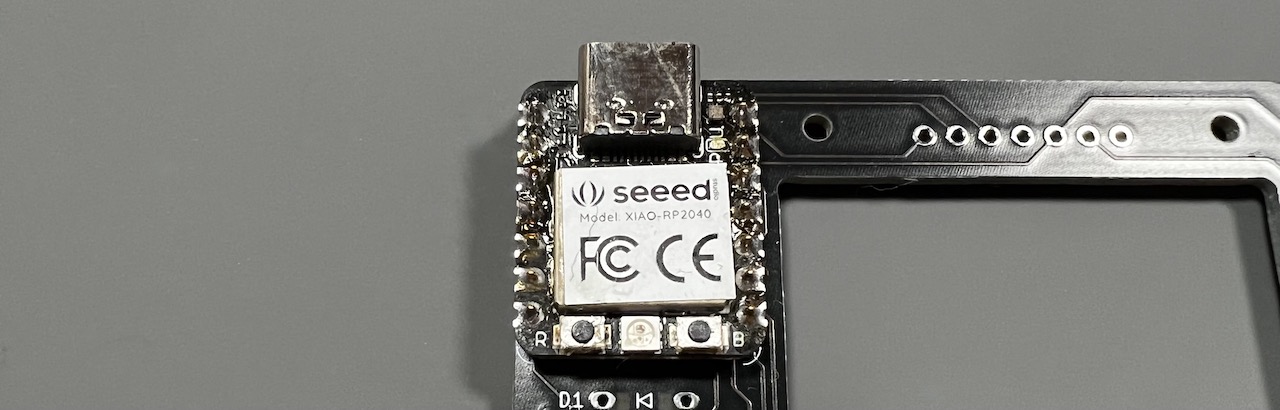
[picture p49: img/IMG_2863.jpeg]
 

USBケーブルを接続してLEDが発光することを確かめてください。光らない場合は向きが間違っていたりどこかでショートしていたりはんだ付けが足りない可能性があります。  
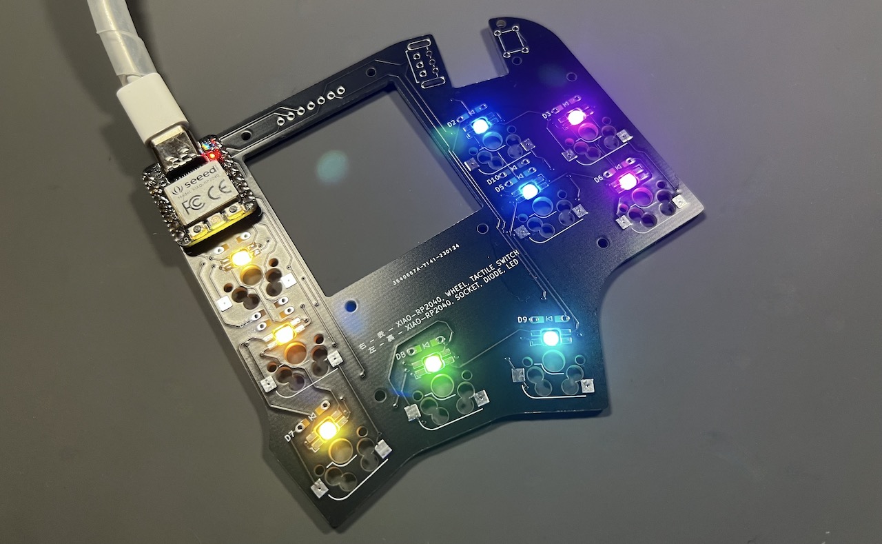
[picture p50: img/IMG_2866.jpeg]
  
  
USBケーブルを抜いてください。はんだ付けの作業は通電していない状態で行います。    
この後も部品を取り付けるごとにその部品の動作を確認するとトラブルの原因を突き止めやすいです。   
    
ダイオードを折り曲げて差し込み、固定するためにさらに曲げます。表裏を指定してありますがどちら側でも構いません。  
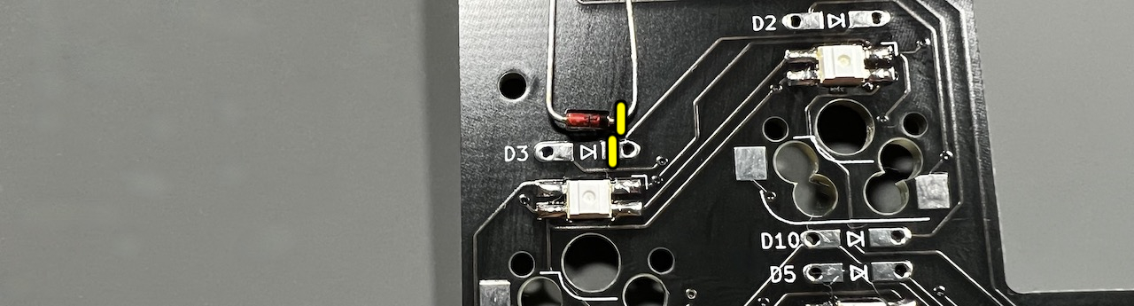
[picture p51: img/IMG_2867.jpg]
 
ダイオードには向きがあるので、黒線と基板の矢印の向きを合わせてください。  

はんだ付けをしたら足をニッパーで切ります。  
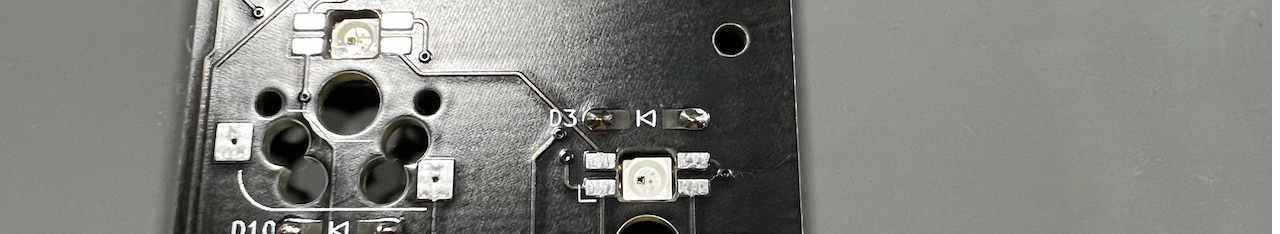
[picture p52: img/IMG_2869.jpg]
 

スイッチソケットをはんだ付けします。裏表に注意してください。  
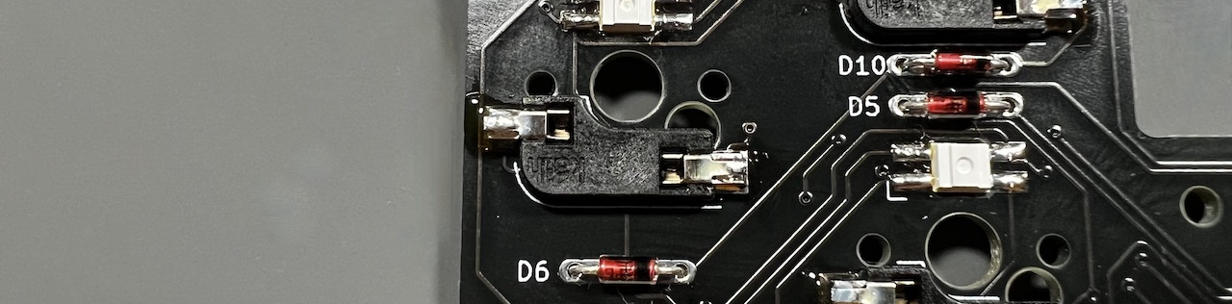
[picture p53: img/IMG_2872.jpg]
 

メインボードにホイールエンコーダーとタクタイルスイッチ（足が下に伸びている方）をはんだ付けします。表裏に注意してください。  
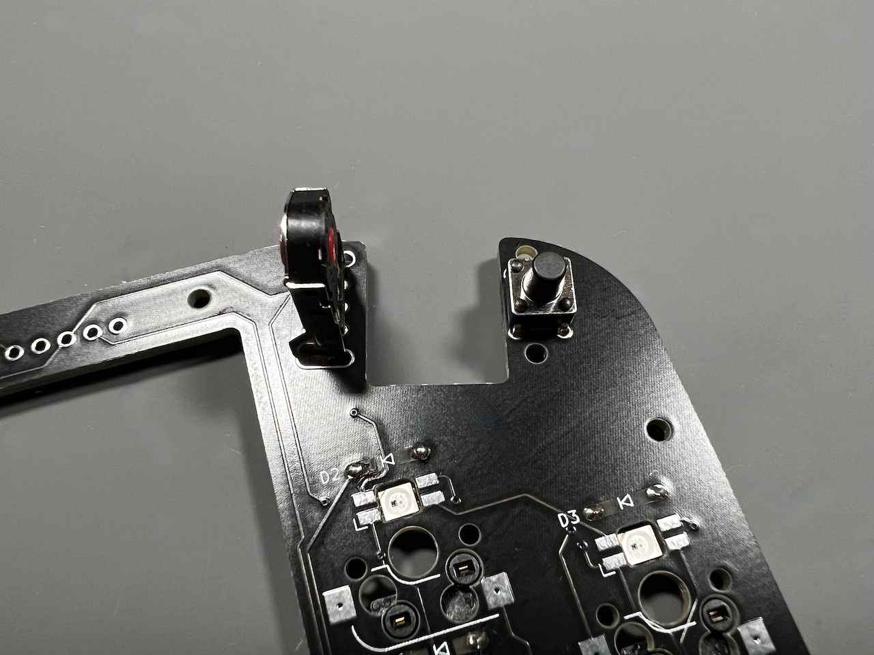
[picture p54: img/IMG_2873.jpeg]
 

ボトムプレートに7ピンヘッダを差し込みます。  
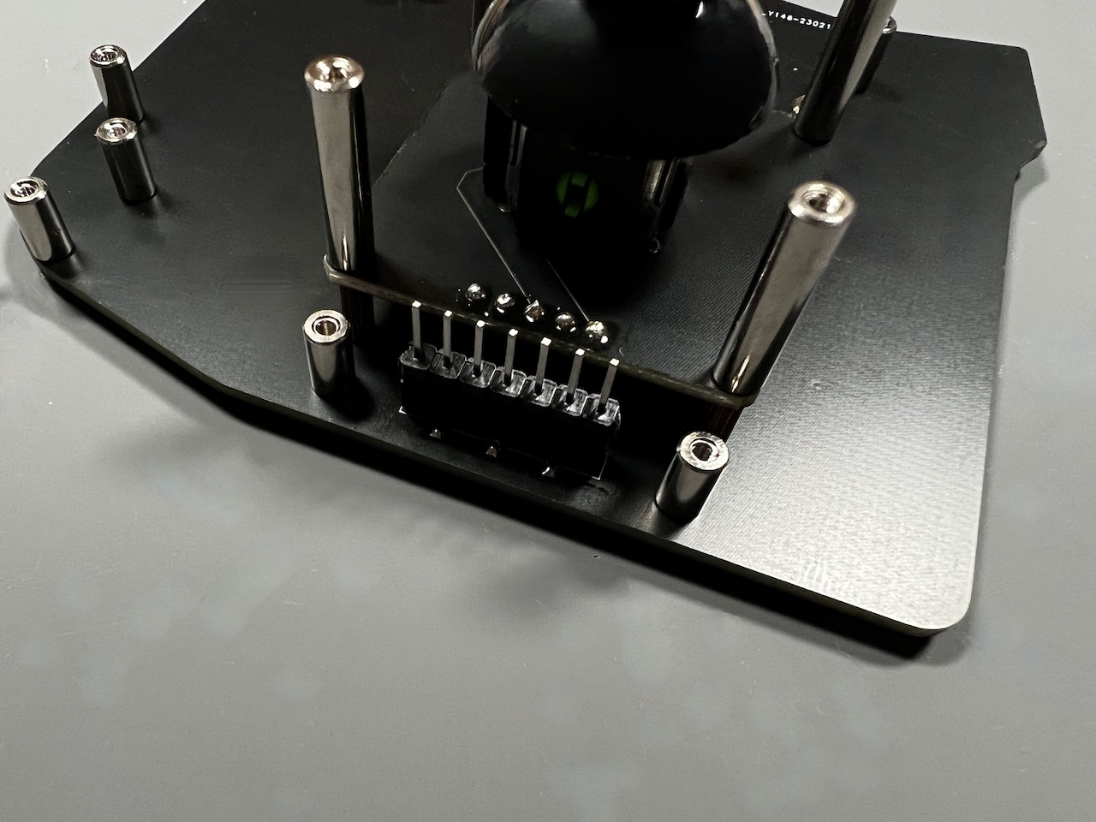
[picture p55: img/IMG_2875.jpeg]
 

ボトムプレートにメインボードを載せ、スペーサー（太）（長）でボトムプレートに固定します。トッププレートで隠れる黄丸の一箇所だけはねじ（短）で止めます。  
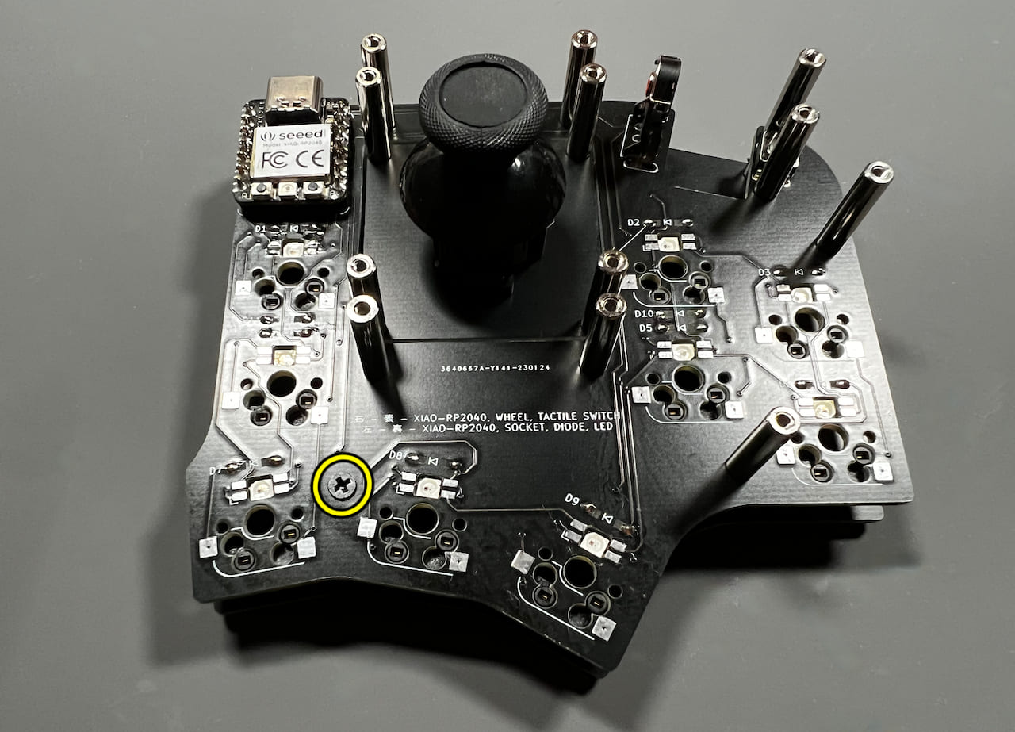
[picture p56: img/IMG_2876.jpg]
 
飛び出たピンヘッダをニッパーで切ってはんだ付けしましょう。テストファームウェアではジョイスティックは動作しません。  
 
トッププレートの4隅にスイッチを差し込みます。差し込みが硬い場合はここですべてのスイッチを固定してしまう方がいいかもしれません（スイッチの種類によって変わります）。  
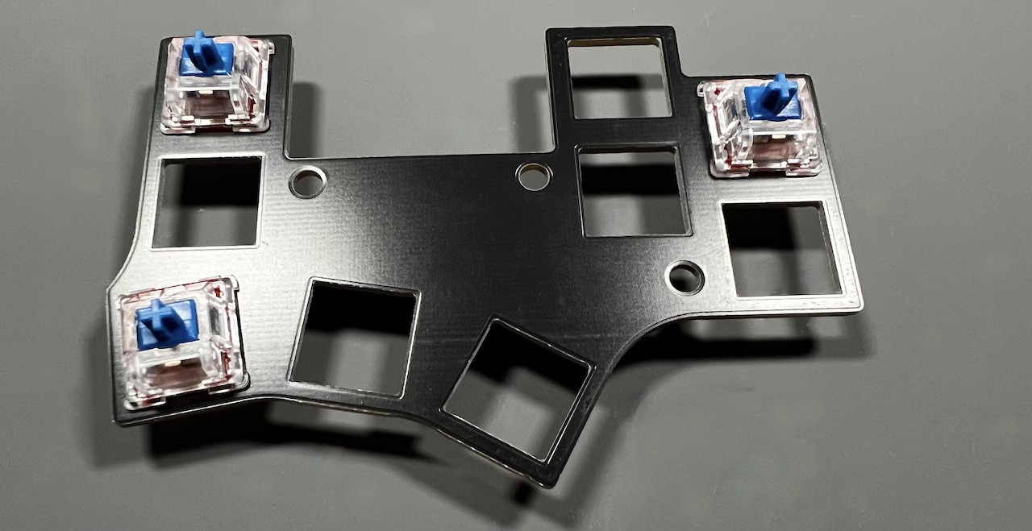
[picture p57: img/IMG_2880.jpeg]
 

スペーサーを通してメインボードに乗せ、キースイッチがスイッチソケットに入るように押し込みます。  
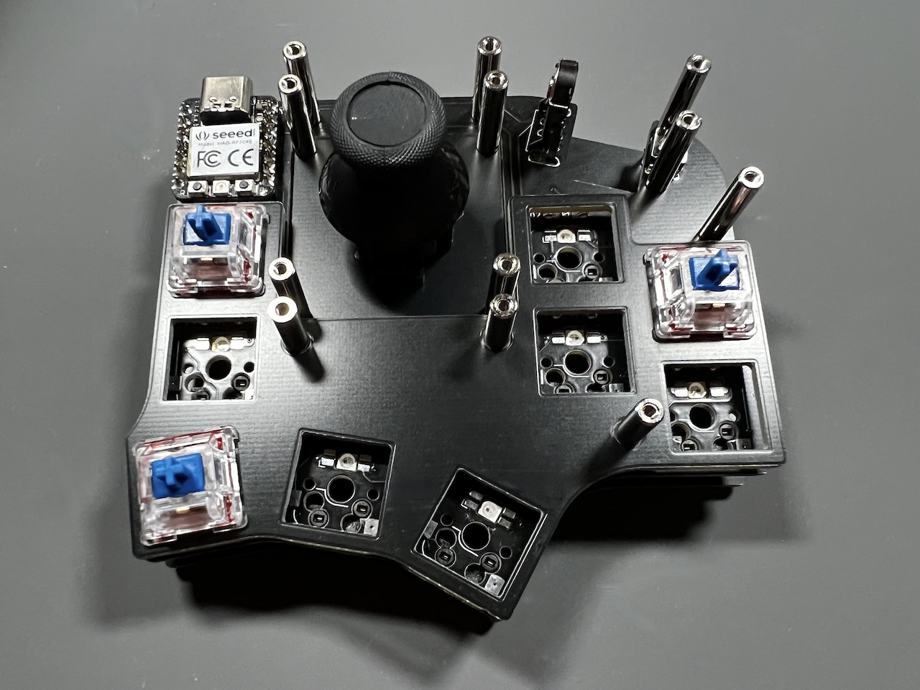
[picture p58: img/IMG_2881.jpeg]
 
キースイッチのピンが曲がらないように気をつけてください。  

全てのスイッチを差し込み、ホイールをホイールエンコーダーに差し込みます。  
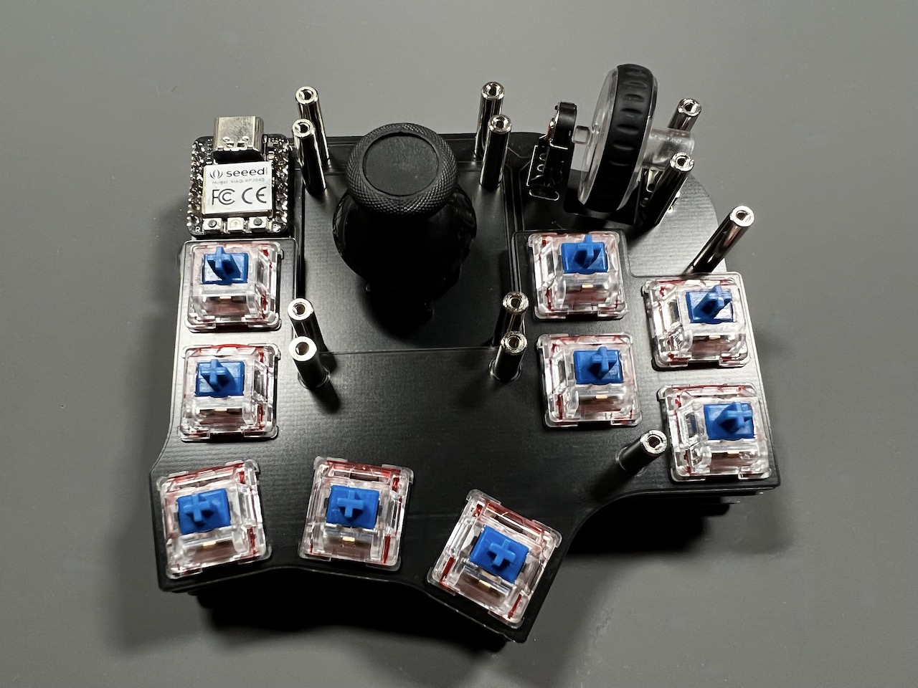
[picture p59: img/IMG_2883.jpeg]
 

アクリルプレートから保護フィルムを剥がして、ねじ（長）で止めます。  
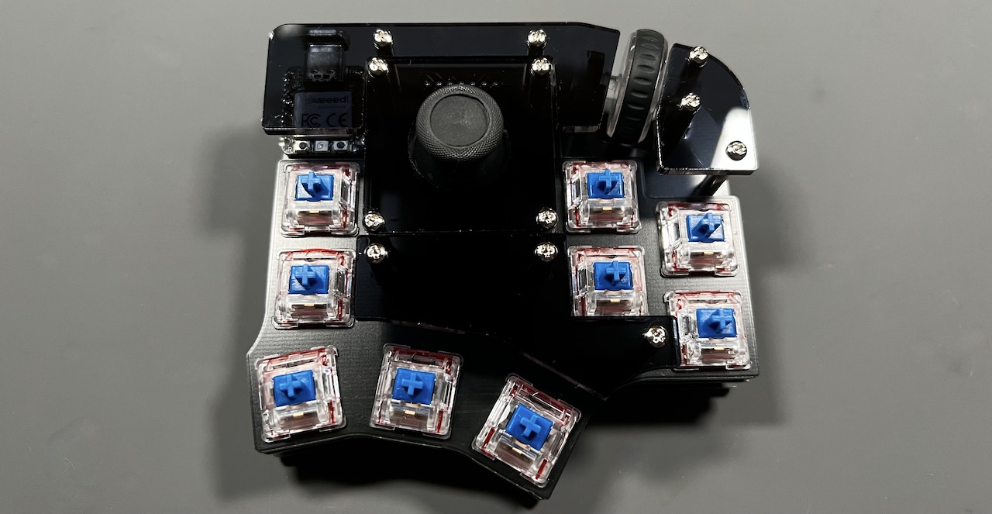
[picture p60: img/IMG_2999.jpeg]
 

キーキャップをつけて完成です。  
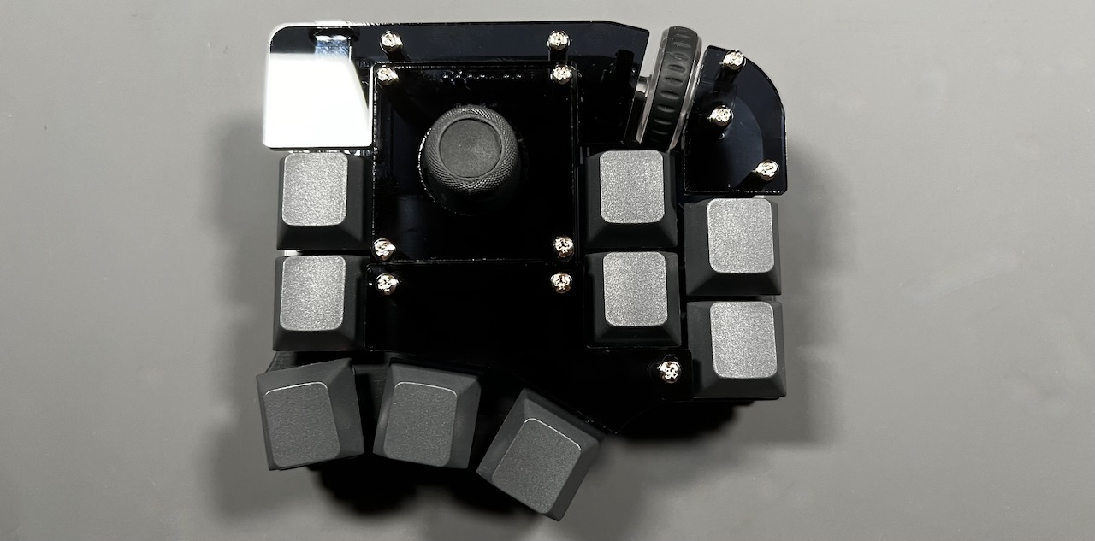
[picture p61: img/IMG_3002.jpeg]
 
こちらのファームウェアを書き込んでください。XIAO RP2040のBのスイッチを押す代わりに、XIAO RP2040に一番近いキーを押しながらUSBケーブルを繋ぐことでRPI-RP2のドライブを出すことが出来ます。  
- [tarohayashi_kombucha_stick_stick.uf2](https://github.com/Taro-Hayashi/Kombucha2/releases/download/0.20.7/tarohayashi_kombucha_stick_stick.uf2)
- 後期型向け [tarohayashi_kombucha_stick_stick.uf2](https://github.com/Taro-Hayashi/Kombucha2/releases/download/0.20.8/tarohayashi_kombucha_stick_stick.uf2)

## カスタマイズ
LEDを消したい時は親指クラスタ（最下段）の奥のキーを押しながらジョイスティックを押し込んでください。  
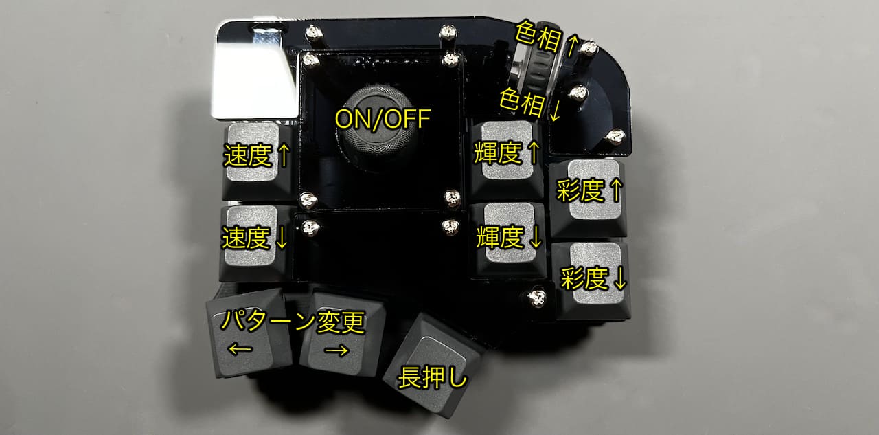
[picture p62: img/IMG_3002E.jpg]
 
  
ジョイスティックを含めた全てのキーはVIAというWebサイト（もしくはアプリケーション）で好きなものに変更することができます。  
こちらのJSONファイルをダウンロードしてください。 
- [kombucha.json](https://github.com/Taro-Hayashi/Kombucha2/releases/download/0.20.0/kombucha.json)

Google Chrome（Microsoft Edge）を利用して下記webサイトにアクセスするか、VIAのアプリケーションをダウンロードして起動してください。  
- [Web版VIA（Google Chromeでアクセスしてください）](https://usevia.app/#/design)
- [アプリ版VIA](https://github.com/the-via/releases/releases)

DESIGNタブのLoadでダウンロードしたJSONファイルを読み込ませるとキーの変更が出来るようになります（アプリ版ではまずShow Design tabをオンにしてください）。  
  
CONFIGUREタブのAuthorize device+からKombuchaを追加してください。  

### 左右の変更
LAYOUTSから見た目の左右を変更することができます。  
  

### ホイールの割り当てキー
キーマップ変更画面で上部の丸をクリックするとホイールを回転させた時と押し込んだ時に入力されるキーを変更することができます。  
  

### その他の利用方法
ジョイスティックでマウスカーソルを動かすことも可能で、その場合はこちらのファイルをダウンロードしてファームウェアを書き換えてください。 
- [tarohayashi_kombucha_stick_cursor_left.uf2](https://github.com/Taro-Hayashi/Kombucha2/releases/download/0.20.7/tarohayashi_kombucha_stick_cursor.uf2)
- 後期型向け [tarohayashi_kombucha_stick_cursor.uf2](https://github.com/Taro-Hayashi/Kombucha2/releases/download/0.20.8/tarohayashi_kombucha_stick_cursor.uf2)

認識が不安定ですが、こちらのファームウェアを書き込むことでKombuchaをゲームパッドとして認識させることもできます。
- [tarohayashi_kombucha_sitck_joypad_fix.uf2](https://github.com/Taro-Hayashi/Kombucha2/releases/download/0.20.7/tarohayashi_kombucha_stick_joypad.uf2)

標準では親指クラスタの真ん中のキーを長押しでカーソル/ジョイパッドの方向を変更できます。
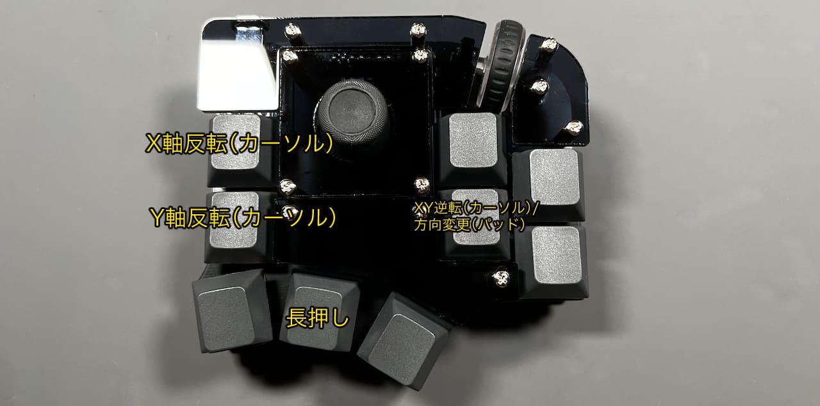
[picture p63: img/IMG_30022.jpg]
  

|機能（カーソル）|機能（パッド）|キーコード|
|-|-|-|
|X軸反転||CUSTOM(65)|
|Y軸反転||CUSTOM(66)|
|XY逆転|方向変更|CUSTOM(67)|

SPECIALタブのAnyで割り当てることができます。

 
  
#### ジョイスティックの補正
#### ジョイスティックの補正
WindowsではスタートメニューにJOY.CPLと打ち込むとスティックの補正ができます。  
  
プロパティから調整を選びウィザードに従ってください。  
  
上手く動かない場合はゲームパッドとしてではなく通常のファームウェアにカーソルキーやWASDを割り当ててお使いください。  

## meishi Trackball Moduleを使う
### はんだ付け
一度分解し、ボトムプレートにタクタイルスイッチSMDをはんだ付けします。  
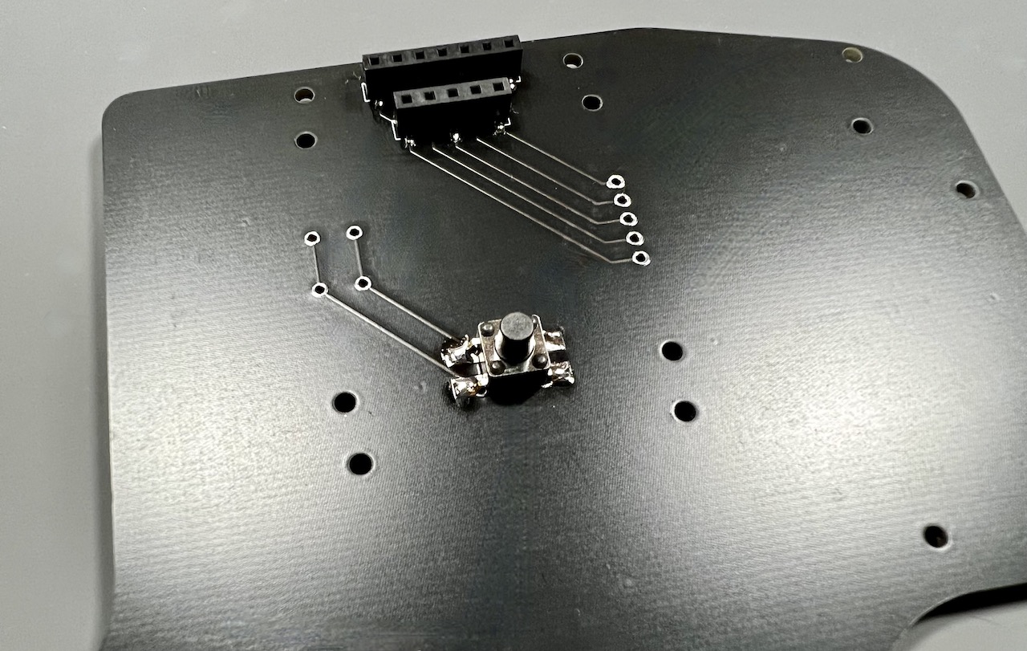
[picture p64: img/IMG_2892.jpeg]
  
ピンヘッダーが有る側の2箇所はスペーサー（細）（長）、無い側の2箇所はスペーサー（細）（短）をねじ止めします。  
 
meishi Trackball Moduleを基板から切り離してください。  
[meishi Trackball Module互換基板を使う場合はこちらをご覧ください。](mTM.md)  
  
ジョイスティックの時と同様にピンヘッダを立てモジュール付属のねじを使って基板の位置を決めたらはんだ付けします。  
  
後期型の場合は画像のピンを開けて差し込んでください。違っているとネジ穴が合わないので確認してから半田付けしてください。
  
はんだ付けをしたらねじを一度はずしてモジュール基板を取り外し、センサーの保護フィルムをはがしてレンズとボールケースを取り付けます。  
  
ピンヘッダーのない側にスペーサー（細）（短）をねじで止めます。  
  
スペーサーの上にスプリングを立てます。  

ねじでスペーサー（細）（長）側も止めるとボールのクリックができるようになります。  

組み立て直したら完成です。  


ファームウェアはこちらをお使いください。  
- [tarohayashi_kombucha_ball_via.uf2](https://github.com/Taro-Hayashi/Kombucha2/releases/download/0.20.7/tarohayashi_kombucha_ball_via.uf2)

### トラックボールの調整
標準では親指クラスタの真ん中のキーを押しながらボールの左右のキーを押すとセンサーの感度（CPI）を増減できます。その下のキーを押すとマウスカーソルの上下左右の十字方向と10°の微調整が可能です。  

|機能|キーコード|
|-|-|
|CPI増|CUSTOM(65)|
|CPI増|CUSTOM(66)|
|角度増|CUSTOM(67)|
|角度減|CUSTOM(67)|

SPECIALタブのAnyで割り当てることができます。

 

## その他
### ファームウェアのフォルダ
- https://github.com/Taro-Hayashi/qmk_firmware/tree/tarohayashi/keyboards/tarohayashi/kombucha

### ファームウェアまとめ
※5/9  
tarohayashi_kombucha_stick_cursor.uf2:カーソル用のファームウェアを一つにまとめました  
tarohayashi_kombucha_sitck_joypad.uf2:スティックの方向の設定が保存されるようにしました  
tarohayashi_kombucha_ball_via.uf2:カーソルの方向、速度の設定が保存されるようにしました  
- テスト用 [tarohayashi_kombucha_stick_default.uf2](https://github.com/Taro-Hayashi/Kombucha2/releases/download/0.20.7/tarohayashi_kombucha_stick_default.uf2)
- スティックにキー割り当て [tarohayashi_kombucha_stick_stick.uf2](https://github.com/Taro-Hayashi/Kombucha2/releases/download/0.20.7/tarohayashi_kombucha_stick_stick.uf2)
- スティックにキー割り当て（後期型向け） [tarohayashi_kombucha_stick_stick.uf2](https://github.com/Taro-Hayashi/Kombucha2/releases/download/0.20.8/tarohayashi_kombucha_stick_stick.uf2)
- スティックにマウスカーソル [tarohayashi_kombucha_stick_cursor.uf2](https://github.com/Taro-Hayashi/Kombucha2/releases/download/0.20.7/tarohayashi_kombucha_stick_cursor.uf2)
- スティックにマウスカーソル（後期型向け） [tarohayashi_kombucha_stick_cursor.uf2](https://github.com/Taro-Hayashi/Kombucha2/releases/download/0.20.8/tarohayashi_kombucha_stick_cursor.uf2)
- ジョイパッド[tarohayashi_kombucha_sitck_joypad.uf2](https://github.com/Taro-Hayashi/Kombucha2/releases/download/0.20.7/tarohayashi_kombucha_stick_joypad.uf2)
- トラックボール [tarohayashi_kombucha_ball_via.uf2](https://github.com/Taro-Hayashi/Kombucha2/releases/download/0.20.8/tarohayashi_kombucha_ball_via.uf2)

### VIA用JSON
- [kombucha.json](https://github.com/Taro-Hayashi/Kombucha2/releases/download/0.20.0/kombucha.json)

### アクリルプレートのデータ
DXF、SVG、kicadファイルが入っています。
- [kombucha_acrylic.zip](https://github.com/Taro-Hayashi/Kombucha2/releases/download/0.19.12%2Fdevelop/kombucha_acrylic.zip)

### 謝辞
aki27さんのコードを参考にトラックボール用のファームウェアを書きました。  
- URL　https://github.com/aki27kbd/qmk_firmware
- ライセンス https://github.com/aki27kbd/qmk_firmware/blob/master/LICENSE

### 販売サイト  
- BOOTH: https://tarohayashi.booth.pm/items/3252673

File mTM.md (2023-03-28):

# meishi Trackball Module互換基板キットの組み立て方
※販売終了のため別ページに分けました。いずれリンクを外しますので、見当たらない場合はリポジトリのファイル一覧から閲覧してください。

袋の番号を確認しながら部品をはんだ付けします。
  
抵抗やコンデンサーは小袋から出すと見分けが付かなくなるので1種類ずつはんだ付けしてください。
  
LEDをはんだ付けします。
  
センサーをはんだ付けします。

ブラウザの機能で戻ってください。

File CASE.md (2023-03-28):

# Kombucha ジョイスティック アクリル積層ケース

## キット内容
|部品|数||
|-|-|-|
|トッププレート|1||
|ミドルプレート|10||
|ボトムプレート|1||
|スペーサー|6|[27mm](https://www.hirosugi-net.co.jp/shop/g/g2418/)|

## 組み立て
キットをご購入の場合は組み立てられた状態で届くのでネジを外して一度分解してください。

Kombuchaのアクリルプレートを外します。

保護フィルムを外したトッププレートを載せてねじ止めします。空いたネジ穴にスペーサーを取り付けます。

USB部分が開くように重ねます（隙間のあるミドルプレートの枚数が５枚のものと6枚のものがあります）。

ボトムプレートを取り付けます。

ゴム足を貼ったら完成です。


## ケースのデータ
### 元になるデータ
- [kombucha_acrylic_case.zip](https://github.com/Taro-Hayashi/Kombucha2/releases/download/0.20.0/kombucha_acrylic_case.zip)
  
kicadファイル、SVGファイル、DXFファイルが入っています。厚みは3mmです。各種サービスのルールに沿ってテンプレートに並べ替えたり線幅、色などを調節してください。  
Elecrowさんの少し薄い（2.8mm程度）のアクリル板を前提に設計しているので、国内サービスの精度の高い3mmのアクリルを使用した場合はスペーサーの長さ、使うミドルプレートの枚数等を現物に合わせていただく必要があるかもしれません。

### Elecrow向けファイル
- [kombucha_acrylic_case_elecrow.zip](https://github.com/Taro-Hayashi/Kombucha2/releases/download/0.20.0/kombucha_acrylic_case_elecrow.zip)
  
こちらのZipファイルでElecrowさんで注文すると1ケース分揃います。
287.3x139.4mm、数量5枚、厚みは3mm、お好みの色で発注してください。

何かあった場合は英語でのやりとりになりますのでご注意ください。

ブラウザの機能で戻ってください。
